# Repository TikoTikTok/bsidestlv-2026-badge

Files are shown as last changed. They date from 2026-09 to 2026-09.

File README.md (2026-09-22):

# BSidesTLV 2026 Badge

Everything for the BSidesTLV 2026 badge: two KiCad boards, the RP2040 firmware
that runs on it, and the online puzzle challenge — *Alice in AI Land* — that the
badge is used to play.

<p align="center">
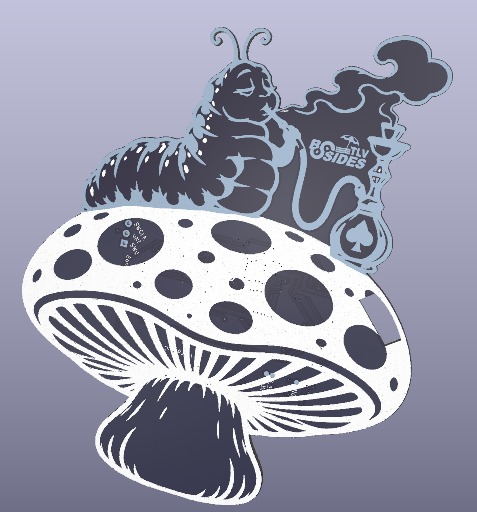
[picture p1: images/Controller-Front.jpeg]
The badge, front
  
</p>

```
index.html         the challenge - static site, served from the repo root
styles.css  src/  stages/  assets/
hardware/          KiCad projects (CERN-OHL-S-2.0)
  badge/             "BSidesTLV2026 Alice Controller" - RP2040 handheld, 14 buttons, USB-C
  soldering-kit/     555 + CD4017 LED chaser, the soldering workshop kit
software/          everything that builds the above, but is not served (MIT)
  controller/        RP2040 firmware - enumerates as a DualShock 4
  tools/             slicing and generation, writes into ../assets/
  references/        the source sheets the art was cut from
  legacy/  docs/
```

## The challenge

*Alice in AI Land* is a boulder-pushing puzzle game whose answer is a **program**.
Five stages. The first two are played by hand on the badge. Stage 3 is a
wall: the board is hidden before a human could read it and the move budget
exceeds human input bandwidth, so the only way through is to drive the game with
a script. The game hands you the protocol in stage 2 and dares you to use it.

The simulation is deterministic — 60 ticks/second, one input bitmask per tick,
same seed plus same input trace gives the same outcome byte for byte — which is
what makes it scriptable, replayable and verifiable.

It lives at the repository root — `index.html`, `styles.css`, `src/`, `stages/`
and `assets/` — as plain static files. No server, no build step, every path
relative, so it works at a domain root or under `/<repo>/` unchanged.

```
./serve.sh          # http://localhost:8080, the same files Pages serves
npm run verify      # proves both stages are solvable
```

[`.github/workflows/pages.yml`](.github/workflows/pages.yml) stages those five
paths and publishes them; set Settings -> Pages -> Source to "GitHub Actions"
once and pushes to `main` that touch the site deploy themselves. It stages
rather than uploading the repo so the artifact stays ~4MB instead of ~34MB —
`hardware/` and `software/` are not part of the site.

ES modules need `http://`, not `file://`. That is the only reason a local
server exists.

- [`software/README.md`](software/README.md) — asset set, slicing tools, how every sprite was cut
- [`software/docs/GAME_DESIGN.md`](software/docs/GAME_DESIGN.md) — stages, tick model, protocol

## The hardware

| Board | What | Key parts |
|---|---|---|
| [`hardware/badge/`](hardware/badge) | "BSidesTLV2026 Alice Controller" v0.4 — the badge itself, and the controller the challenge is played on. D-pad, A/B/X/Y, Start/Select, reset and BootSel, all on one side. Cut to the outline of the Caterpillar's mushroom. | RP2040, W25Q128JVS, AMS1117-3.3, USB-C |
| [`hardware/soldering-kit/`](hardware/soldering-kit) | Through-hole LED chaser for the soldering workshop. Beginner-friendly: DIP, axial, CR2032. | TLC555P, CD4017BE, 4x LED, 500k trimmer |

<table>
<tr>
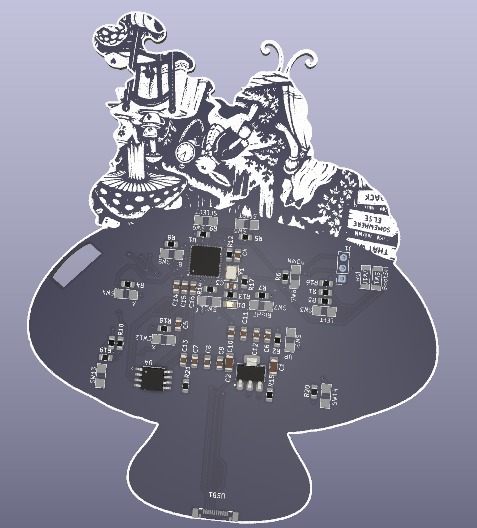
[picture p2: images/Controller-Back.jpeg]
The badge, back
  <td align="center" width="50%"></td>
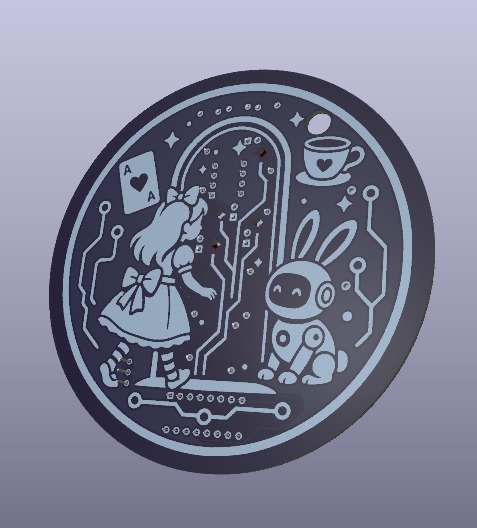
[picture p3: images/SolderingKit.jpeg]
The soldering kit
  <td align="center" width="50%"></td>
</tr>
<tr>
  <td align="center"><b>badge, back</b> — the RP2040, flash, regulator and the button matrix</td>
  <td align="center"><b>soldering kit</b> — Alice, the White Rabbit and the looking glass</td>
</tr>
</table>

Each project carries its own `production/` directory with the fabrication
package: BOM, positions, designators and IPC netlist.

See [`hardware/README.md`](hardware/README.md) for opening, plotting and
re-fabricating the boards.

## The firmware

[`software/controller/`](software/controller) is the RP2040 firmware. It
presents the badge to a host as a **wired DualShock 4**, which is what makes it
work on an iPhone — iOS only binds controllers it recognizes by USB VID/PID, so
a generic HID gamepad enumerates and is then ignored. Every other host
understands the same report.

```
cd software/controller
mkdir build && cd build
cmake -DPICO_SDK_PATH=/path/to/pico-sdk ..
make -j                              # -> build/controller.uf2
```

Hold `BootSel` while plugging in USB-C, then copy `controller.uf2` onto the
`RPI-RP2` drive that appears. It also builds and runs on a stock Raspberry Pi
Pico, which is the easiest way to try the firmware without a badge.

Full pin map and HID report layout:
[`software/controller/README.md`](software/controller/README.md).

## Licences

- **Software** — MIT, see [`LICENSE`](LICENSE). Covers `software/` and the
  Python/Node tooling under `hardware/soldering-kit/tools/`.
- **Hardware** — CERN-OHL-S-2.0, see [`hardware/LICENSE`](hardware/LICENSE).
  Covers both KiCad projects and every gerber, plot and production package
  under `hardware/`.

Third-party symbols and footprints vendored under
`hardware/badge/libs/lcsc/` keep their own upstream terms.

## Contributing

See [`CONTRIBUTING.md`](CONTRIBUTING.md).

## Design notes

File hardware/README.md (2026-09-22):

# Hardware

Two KiCad 9 projects. Each is self-contained: open the `.kicad_pro` in KiCad
and everything it needs is beside it.

| Directory | Project | What it is |
|---|---|---|
| `badge/` | `PhoneController` / "BSidesTLV2026 Alice Controller" v0.4 | The badge, and the controller the online challenge is played on: D-pad, A/B/X/Y, Start/Select, reset and BootSel, USB-C, 16 MB external flash, SWD header. |
| `soldering-kit/` | `BSidesTLV26TinyBadge` | The soldering workshop kit: a TLC555 astable clocking a CD4017 decade counter that chases four LEDs. All through-hole — DIP sockets, axial resistors, a 3296W trimmer for the rate and a CR2032 holder — so a first-time solderer can build it. |

The project files inside `badge/` are still named `PhoneController.*` — that
was the board's working name before it became the badge. The directory says what
it is; renaming the KiCad project would break every path that refers to it.

## Opening

KiCad 9. Nothing here needs a plugin to *view*; the production packages were
generated with [Fabrication Toolkit](https://github.com/bennymeg/Fabrication-Toolkit),
whose settings live in each project's `fabrication-toolkit-options.json`.

`badge/libs/lcsc/` vendors the symbol, footprint and 3D model for the USB-C
connector imported from LCSC. `fp-lib-table` and `sym-lib-table` point at it
with project-relative paths, so the project moves without breaking.

## Fabrication

Each project ships the package it was last ordered with:

```
<project>/production/
  bom.csv           designator -> footprint, quantity, value, LCSC part number
  positions.csv     pick-and-place
  designators.csv
  netlist.ipc       IPC-D-356 netlist, for bare-board electrical test
  <project>.zip     the gerbers as sent to the fab
```

`badge/gerbers/` additionally keeps the loose gerber set and job file, and
`badge/output/` the per-layer SVG plots.

To regenerate rather than reuse: open the board, run Fabrication Toolkit, and
the directory is rewritten.

## Generating the soldering-kit schematic

`soldering-kit/tools/` builds `BSidesTLV26TinyBadge.kicad_sch` from code rather
than by hand:

```
python3 soldering-kit/tools/build_badge_sch.py
```

| File | What |
|---|---|
| `build_badge_sch.py` | The circuit itself: CR2032 -> TLC555 astable -> CD4017 -> 4 LEDs, with the part choices argued in its docstring |
| `schbuild.py` | Places symbols, resolves absolute pin coordinates, draws wires |
| `symlib.py` | Pulls a symbol out of a `.kicad_sym` library, flattening `(extends ...)` so the embedded copy is self-contained |
| `ksexpr.py` | Dependency-free S-expression reader/writer that round-trips KiCad files |
| `verify_xf.py` | Regression check for the pin transform against a pre-change schematic passed as `argv[1]` |

These are software, not hardware: MIT, under the root `LICENSE`.

## Autorouting

`badge/freerouting.dsn` is the Specctra export used with
[Freerouting](https://github.com/freerouting/freerouting). It is an export, not
a source of truth — the `.kicad_pcb` is.

## What is deliberately not here

KiCad's own rolling archives (`*-backups/`, `production/backups/`), the
`fp-info-cache`, `*.kicad_prl` per-user state and editor lock files are all
ignored — git is the history now. See the root `.gitignore`.

## Firmware

The badge's firmware is not here — it is a Pico SDK project at
[`../software/controller/`](../software/controller), under MIT like the rest of
the software.

## Licence

CERN-OHL-S-2.0, see [`LICENSE`](LICENSE). Vendored third-party libraries under
`badge/libs/` keep their upstream terms.

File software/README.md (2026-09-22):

# Alice in AI Land — asset set

Characters and items for a boulder-pushing puzzle game, cut from the supplied
reference sheets. Everything on the page is real art: nothing is generated.

```
./serve.sh        # http://localhost:8080
```

ES modules need `http://`, not `file://`. That is the whole build system.

## Layout

The site itself is at the repository root — `index.html`, `styles.css`, `src/`,
`stages/`, `assets/` — because that is what GitHub Pages serves. This directory
is everything that produces it and is never published:

```
tools/        slicing and generation, writes into ../assets/
references/   the source sheets the art was cut from (15MB)
docs/         design doc
legacy/       the generated-sprite pass the page no longer loads
controller/   RP2040 firmware for the badge - a separate CMake project
```

Run the tools from the repository root, where `package.json` lives:

```
npm run verify      # both stages solvable
npm run validate    # legacy sprite/frame integrity
./serve.sh          # http://localhost:8080
```

`controller/` is the firmware the badge runs — a Pico SDK CMake project with its
own [README](controller/README.md), unrelated to those npm scripts.

Deployment is [`.github/workflows/pages.yml`](../.github/workflows/pages.yml).

## What's here

| Path | What |
|---|---|
| `assets/characters/<name>/` | 24 walk frames (8 directions x 3), 48x48 RGBA, + `<name>.json` |
| `assets/items/` | 44 item PNGs, 48x48 RGBA, + `items.json` |
| `assets/tiles/` | 77 floor, wall, hedge, rail, door and button PNGs, 48x48 RGBA, + `tiles.json` |
| `software/references/` | The supplied reference sheets every asset was cut from |
| `tools/slice-walk-grid.py` | Cuts a character sheet into walk frames |
| `tools/slice-item-sheet.py` | Cuts `software/references/assets-reference.png` into items |
| `tools/slice-tile-sheet.py` | Cuts `software/references/tiles-reference.png` into tiles and props |
| `tools/build-walk-manifest.mjs` | Indexes a character folder into `<name>.json` |
| `tools/sheet-maps/` | Hand-picked cell maps for sheets that are not clean grids |
| `tools/pnglib.py` | Dependency-free PNG read/write + black-background keying |
| `tools/preview/` | Look at what a slice produced: contact sheets, sheet cells, side-by-side frames |
| `index.html`, `src/`, `styles.css` | The page: two playable stages, walk cycles, tile and item sheets |

## Characters

| character | folder | source sheet | how |
|---|---|---|---|
| Alice | `alice2/` | `software/references/alice-reference3.png` | cut by hand |
| White Rabbit | `rabbit/` | `software/references/white-rabbit-reference.png` | `slice-walk-grid.py` (wide) |
| Mad Hatter | `hatter/` | `software/references/mad-hatter-reference.png` | `slice-walk-grid.py` + cell map |
| Red Queen | `queen/` | `software/references/queen-reference.png` | `slice-walk-grid.py` + cell map |
| Cheshire Cat | `cheshire/` | `software/references/cheshire-reference.png` | `slice-walk-grid.py --layout pairs` |

Frames are `<dir><frame>.png` (`s1.png`, `N1.png`, `SW2.png` - case does not
matter). Frame 1 stands, 2 and 3 are the walk pair; the manifest's `cycle` runs
them as stand → step → stand → other step.

```
python3 software/tools/slice-walk-grid.py software/references/white-rabbit-reference.png rabbit
node software/tools/build-walk-manifest.mjs assets/characters/rabbit rabbit
```

**Layouts.** `--layout wide` (default) is 8 columns x 3 rows, one column per
direction. `--layout pairs` is 6 columns x 4 rows — two directions per row —
which is how the Cheshire sheet is arranged.

**Sheets without an alpha channel** (queen, cheshire) sit on pure black. The
tool floods in from the border through *pure* black only, so the background goes
and the character's near-black outline stays; nothing inside the figure is
reachable, so it cannot punch holes.

**Pose sheets.** The hatter and queen sheets are not direction grids — the
facing drifts across each row. `tools/sheet-maps/<name>.json` names the cells to
use per direction, which are mirrored, and which are aliases:

```json
{ "cells":  { "n": [[1,1],[1,8],[1,7]], "sw": [[2,3],[2,2],[2,1]] },
  "mirror": { "ne": "nw", "se": "sw" },
  "alias":  { "w": "sw", "e": "se" } }
```

Direction follows the **body**, not the head — in these sheets a character often
walks one way while glancing back over their shoulder. Reading the face gets the
mapping backwards.

Known compromises, both from the source sheets: the hatter has no true profile,
so his E and W reuse the diagonals; the queen has only two usable side poses, so
her W repeats a frame.

## Tiles

```
python3 software/tools/slice-tile-sheet.py
```

Cuts both tile sheets - `software/references/tiles-reference.png` and `software/references/assets-reference2.png` - into
77 assets under `assets/tiles/`, with one merged manifest and two fit policies,
because these are two kinds of art:

- **tile** (`floor`, `wall`) fills the whole 48x48 cell — these *are* the grid,
  and a gap around them would read as a seam.
- **prop** (`door`, `button`) keeps its aspect and sits on the cell floor, all
  sharing one scale factor so a button stays smaller than a door.

The sheets carry a faint coloured halo around some sprites (alpha 1-4, stray
blues and yellows). Weighting the resample by alpha makes it contribute
essentially nothing, so no keying or clean-up pass touches the colours.

Rows are found from the pixels, except on the second sheet where the walls in
neighbouring rows nearly touch; those band boundaries are given explicitly,
found from the row-occupancy profile rather than from gaps.

**Not every wall piece fills its cell.** Pillars, posts and rails are narrower
than 48px, so the stages draw a floor in every cell first and composite the
wall art on top. Without that, the gap around a pillar is just background
showing through.

## Items

```
python3 software/tools/slice-item-sheet.py
```

Rows and the items inside each row are found from the pixels, so the last row
holding eight instead of six needs no special case. Every item is scaled by one
shared factor — a key stays small next to a boulder — then centred on the bottom
of a 48x48 frame, the same size as a character frame, so items and characters
drop onto the same grid with no per-asset fiddling.

Categories: `scenery` (rocks, mushrooms), `book`, `teapot`, `teacup`, `potion`,
`token` (keys and cards). Names are in `assets/items/items.json`.

## The stage and the solver

`stages/tea-party.js` is a playable Sokoban-with-extras room. `src/puzzle.js`
holds the rules and the solver; `tools/verify-stage.mjs` runs the same solver
from the command line.

```
node software/tools/verify-stage.mjs stages/tea-party.js
```

```
A Mad Tea Party - 13x9, 3 rocks, 3 buttons, 1 gate(s), 1 lever(s)
solved in 106 moves (330ms, 12520 nodes, 12520 states)
gate: load-bearing - unsolvable when welded shut
```

The verifier does three things worth having:

1. **Replays the solution through the rules.** A solver that returns a path the
   game rejects is a bug, and this catches it — it caught one where the search
   walked Alice through the door cell.
2. **Proves the gate matters.** It re-solves the stage with the gate welded shut
   and the lever removed. "The solver happened to use it" is not the same as
   "the puzzle needs it" — a route that merely exists is not a mechanic.
3. **Reports the shortest solution**, which is the yardstick the tick budgets in
   `docs/GAME_DESIGN.md` are set against.

The **Solve** button on the page runs that same search in the browser and plays
back what it finds. It is not a recorded answer: press it after moving Alice
around by hand and it solves from wherever she is, or tells you the position is
already lost.

### How the search stays fast enough for a button

A step-by-step BFS explores ~750k states on this stage and takes a second or
more. Three changes bring it to ~12k states and ~330ms:

- **Dead squares.** Pull a rock backwards from every button; any square not
  reached that way can never deliver a rock, so a state that puts one there is
  abandoned.
- **Search over pushes, not steps.** Walking between pushes is bookkeeping, not
  a decision. The search branches only where the puzzle does: which rock, which
  way, and when to throw the lever.
- **States keyed by region.** Two spots Alice can walk between without touching
  anything are the same position as far as the puzzle is concerned. Working out
  which region a state belongs to costs a flood fill, so it happens once per
  node popped rather than once per edge considered.

The trade: costs are measured from where Alice actually stands, so the result is
near-optimal rather than provably optimal. Worth two orders of magnitude.

## The timed stage

`stages/queens-gauntlet.js` adds the thing the first stage is missing: a clock.
Every tick the cast advances one cell along a fixed loop, so a plan is not a
route but a schedule.

```
node software/tools/verify-chase.mjs stages/queens-gauntlet.js
```

```
The Queen's Gauntlet - 9x8, 2 rocks, 3 hazards, world repeats every 30 ticks
  queen: 10-tick loop, sight 3
  cheshire: 6-tick loop
  rabbit: 6-tick loop
par 64 ticks (5 of them waiting) - 20.5s at 320ms/tick
hazards: cost 23 extra ticks over an empty room (par 41)
```

`src/chase.js` holds the rules. What makes it searchable is that the hazards
are deterministic and periodic: the world's entire future is
`phase mod period`, so a state is `(Alice, rocks, lever, phase)` and plain
breadth-first search returns the fewest ticks — which is also the stage's par,
the exact number of correct inputs a player has to land.

Why it is hard by hand, and not merely fiddly:

- **One corridor joins the halves and the Queen walks it**, looking three cells
  ahead. Both rocks and Alice have to cross it several times, so every crossing
  is a window rather than a route.
- **Standing still is a move.** The shortest solution waits five times; a player
  who only knows how to move cannot express the plan.
- **Being seen ends the run**, so 64 inputs have to be correct *and* on time.
  One late press and it starts over.

The verifier re-solves the room with the cast removed and reports the
difference. If the hazards cost zero ticks they are scenery, which is exactly
what the first three layouts turned out to be — the map was open enough to
route around everyone.

## The page

Both stages pick their look from a theme: each map character maps to a list of
tiles, and which one a cell gets is a hash of its coordinates - deterministic,
so a room looks hand-dressed but never shuffles between frames. The tea party
is a walled garden, the gauntlet is the Queen's hall.

- **Stage — A Mad Tea Party** — the untimed puzzle. Arrow keys or WASD, R to
  reset, Solve to watch the solver do it. `?autosolve=tea` starts it on load.
- **Stage — The Queen's Gauntlet** — the timed one. The clock runs whether you
  act or not; space waits, R restarts, and the red tint is what the Queen can
  see this tick. `?autosolve=chase` starts it on load.
- **8-way walk cycles** — a tab per character, a compass of all eight directions
  each running its own cycle, and a large view you drive by clicking or with the
  arrow keys / WASD (hold two for a diagonal). `?walk=queen` opens on one.
- **Tiles** and **Items** — every asset, filterable by category, click a name
  to copy it.

Adding a character: drop 24 frames in `assets/characters/<name>/`, run the
manifest tool, add `{ id: '<name>', label: '<Name>' }` to `WALK_CHARACTERS` in
`src/gallery.js`.

## Looking at a slice

Slicing is guesswork until you look at the result, so the review tools are in
the repo rather than improvised each time:

```
python3 software/tools/preview/contact.py assets/characters/queen out.png 3
python3 software/tools/preview/cells.py   software/references/queen-reference.png       out.png
python3 software/tools/preview/compare.py assets/characters/queen   out.png w1,e1,sw1,se1
```

- **contact** renders a whole folder as one sheet — 8x3 for a character,
  manifest order for items and tiles.
- **cells** lays a reference sheet out cell by cell in sheet order, indexed
  `[row, col]` from 1. This is the tool for writing a `sheet-maps/*.json`: it
  shows the grid the way the map file indexes it, so the cells can be read off
  rather than guessed at.
- **compare** puts named frames side by side, big. For settling which way a
  sprite faces — the question that got the queen's mapping wrong three times.

## Legacy

An earlier pass generated placeholder sprites in code. It lives in `legacy/`
(`legacy/assets/sprites.*.js`, `legacy/src/pixel.js`, `legacy/dist/`) and is
driven by `tools/gen-*.mjs`, `tools/export-png.mjs` and `tools/validate.mjs`.
The page no longer loads any of it, and it is outside `` so none of it is
published. Kept only so nothing is deleted without asking — safe to remove.

## Licence

MIT — see the repository root [`LICENSE`](../LICENSE). The hardware this runs on
lives in [`../hardware/`](../hardware) under CERN-OHL-S-2.0.

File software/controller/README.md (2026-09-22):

# Controller firmware

Firmware for the BSidesTLV 2026 badge - the "BSidesTLV2026 Alice Controller" v0.4, a USB HID game
controller built on the RP2040. It also builds and runs unchanged on a stock
Raspberry Pi Pico (RP2040 / RP2350), which is the easiest way to try it without
a badge.

The board it targets is [`hardware/badge/`](../../hardware/badge); this
directory is only the firmware. It enumerates as a **wired DualShock 4**, so
phones, PCs and emulators recognize it with no driver or app - including
iPhones. The button layout mimics a Game Boy Color: a 4-way D-pad plus `A`,
`B`, `X`, `Y`, shoulder buttons (`SR`/`SL`), and `START` / `SELECT`.

### Why DualShock 4 and not a generic gamepad

A plain HID gamepad descriptor works on Android, Windows, macOS and Linux, but
is **invisible on iOS/iPadOS**: Apple's GameController framework only attaches
to controllers it recognizes by USB VID/PID (MFi, Xbox Wireless, DualShock 4 /
DualSense, Switch Pro). A generic gamepad enumerates and is then ignored - no
app can see it. Presenting the DualShock 4's identity and input report makes an
iPhone bind a real controller profile, and every other host understands it too.

## Wiring

All buttons are **active-low**: wire each button between its GPIO and `GND`.
The firmware enables the RP2040's internal pull-ups, so external pull-up
resistors are optional (the description below assumes you already have them).

| Function | GPIO  |
| --- | ----- |
| D-pad DOWN | 0 |
| D-pad RIGHT | 1 |
| D-pad UP | 2 |
| D-pad LEFT | 3 |
| B | 4 |
| A | 5 |
| X | 20 |
| Y | 21 |
| SR (R shoulder) | 22 |
| SL (L shoulder) | 25 |
| START | 23 |
| SELECT | 24 |
| Status LED | 8 |

The status LED (GPIO8, active-high through a current-limiting resistor):

- **Blinks @ 250 ms** — USB not mounted (waiting for host).
- **Blinks @ 1 s** — USB suspended.
- **Solid while pressed** — mounted and running; lights up whenever any button
  is held, as live input feedback.

## HID mapping

The device sends DualShock 4 input report `0x01` (64 bytes) every 5 ms:

| Physical button | DualShock 4 control |
| --- | --- |
| D-pad | Hat switch (8 directions) |
| A | Cross |
| B | Circle |
| X | Square |
| Y | Triangle |
| SR (R shoulder) | R1 |
| SL (L shoulder) | L1 |
| START | Options |
| SELECT | Share |

There are no analog sticks or triggers on the board, so both sticks report
centered (`0x80`) and both triggers report released. Opposing D-pad directions
cancel out (e.g. pressing UP and DOWN together reports centered) so no
impossible diagonal is ever sent.

The report is streamed continuously rather than only on change: the real
controller does the same, and the report counter in `buttons2` has to keep
advancing for drivers that watch it for a stalled device. Feature reports the
host probes during attach (IMU calibration `0x02`, MAC `0x12`, version `0xA3`)
are answered with well-formed placeholder data - see
`tud_hid_get_report_cb()` in `src/usb_descriptors.c`.

## Building

Prerequisites: `cmake` (>= 3.13), the `arm-none-eabi` GCC toolchain, and a
checkout of the [pico-sdk](https://github.com/raspberrypi/pico-sdk) with its
submodules (TinyUSB) initialized.

`CMakeLists.txt` falls back to `../pico-sdk` relative to this directory, which
inside this repository would be `software/pico-sdk` and is almost certainly not
where your SDK lives. Point at it explicitly:

```bash
# from software/controller/
mkdir build && cd build
cmake -DPICO_SDK_PATH=/path/to/pico-sdk ..
make -j
```

`PICO_SDK_PATH` works as an environment variable too, if you already export it.

The first configure fetches `picotool` from git and builds it, so it needs
network access. If you have one already built, reuse it and skip that:

```bash
cmake -DPICO_SDK_PATH=/path/to/pico-sdk -Dpicotool_DIR=/path/to/picotool ..
```

To target a different board (e.g. a Pico 2 / RP2350), pass the board at
configure time:

```bash
cmake -DPICO_BOARD=pico2 -DPICO_SDK_PATH=/path/to/pico-sdk ..
```

The build produces `build/controller.uf2`, about 41KB.

## Flashing

1. Hold the **BOOTSEL** button while plugging the Pico into USB; it mounts as a
   mass-storage drive (`RPI-RP2`).
2. Copy `controller.uf2` onto it. The board reboots and re-enumerates as a
   "Wireless Controller" by "Sony Interactive Entertainment" - see the VID/PID
   note below.

On the badge, BOOTSEL is the button silkscreened `BootSel`; hold it while
plugging in USB-C.

After flashing, plug it into a phone (via USB-OTG / USB-C). It should appear as
a connected gamepad, ready for the challenge at the repository root, for
emulators, or any app that supports HID controllers.

## Notes

- Reports Sony's VID `0x054C` / PID `0x09CC` (DualShock 4 CUH-ZCT2U). That is
  what buys iOS support; it is also not a VID/PID this project owns, so do not
  ship hardware with it.
- **Hardware:** the USB-C receptacle needs a 5.1k Rd pulldown on **both** CC1
  and CC2. CC1 has one (R15 on the controller board); CC2 was left floating,
  which means a USB-C iPhone will not turn on VBUS in one of the two cable
  orientations. `hw/usb/PhoneControllerUSB.kicad_sch` now carries `R1` (5.1k,
  CC2 to GND) - the matching `.kicad_pcb` still needs "Update PCB from
  Schematic" plus placement and routing of that one 0805.
- The RP2040 USB enumeration errata fix (RP2040-E5) is enabled in
  `CMakeLists.txt`; it reserves GPIO15 internally on RP2040 boards.

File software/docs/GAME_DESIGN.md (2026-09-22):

# Alice in AI Land — game design

A puzzle game where the answer is a *program*.

Five stages. The first two are played by hand. Stage 3 is a wall: the board is
hidden before you could read it and the move budget exceeds human input
bandwidth. From there the only way through is to drive the game with a script.
The game does not hide that — it hands you the protocol in stage 2 and dares
you to use it.

---

## 1. Premise

Alice falls into AI Land. Every character is a machine that wants something
from her, and the only currency is moves:

| character | role in play |
|---|---|
| **Alice** | the player's avatar |
| **White Rabbit** | the clock — he paces a fixed route and gates open/close as he passes |
| **Mad Hatter** | rewrites rules: reading his books changes what a button does |
| **Red Queen** | the deadline — she looks at the board on a schedule and removes what offends her |
| **Cheshire Cat** | hides state; after he fades, the board is only visible through the protocol |

---

## 2. Controls

Eight-way movement, because the sprite sheets are eight-way. On a d-pad,
diagonals are two directions held together.

| input | verb |
|---|---|
| D-pad / arrows | step (and push what is in front) |
| **A** | interact — pick up, place, read, unlock |
| **B** | dash — two tiles, does not push |
| **X** | mark / recall — drop a Cheshire mark, press again to swap places with it |
| **Y** | tick-step — advance the world one tick without moving (a wait primitive) |

`Y` matters more than it looks. Puzzles are timing puzzles; a script needs a
no-op that still advances the world, and a human needs a way to stall.

---

## 3. The tick model

Everything is deterministic and discrete. This is what makes the game
scriptable, replayable and verifiable.

- The sim runs at **60 ticks/second**.
- Each tick consumes exactly **one input bitmask**. No input = empty mask.
- Movement has a **cooldown** in ticks, per stage. A move is accepted only when
  the cooldown has expired, so mashing gains nothing.
- Same seed + same input trace = same outcome, byte for byte.

| stage | move cooldown | effective move rate |
|---|---|---|
| 1 | 8 ticks | 7.5 moves/s |
| 2 | 6 ticks | 10 moves/s |
| 3 | 3 ticks | 20 moves/s |
| 4 | 2 ticks | 30 moves/s |
| 5 | 2 ticks | 30 moves/s |

A human sustains roughly **4–6 accurate directional inputs per second** and
reacts to new information in **~250 ms**. Those two numbers are the design
budget: stages 1–2 sit under them, stages 3–5 sit far above.

---

## 4. The Looking Glass protocol

**The server is the game.** It owns the seed, runs the sim, and is the only
authority on state. The browser is just one client rendering what it is told.
A player's script is a client with exactly the same rights. There is no
privileged path, so there is nothing to cheat around — and nothing to
reverse-engineer either. The challenge is the puzzle, not the plumbing.

```
ws://localhost:7777/looking-glass
```

Server → client, once per tick:

```json
{ "tick": 412, "stage": 3, "seed": "b5f1…", "deadline_ms": 14,
  "board": { "w": 9, "h": 9, "tiles": "…", "entities": [ … ] },
  "alice": { "x": 4, "y": 6, "cooldown": 0, "carrying": null },
  "timer": { "remaining_ticks": 58 }, "status": "running" }
```

Client → server:

```json
{ "tick": 412, "buttons": ["up", "left", "a"] }
```

Rules:

- An input is bound to the tick it names. Late inputs are dropped, not queued —
  otherwise a slow script would drift and blame the game.
- One input per tick, maximum. Spam is not a strategy.
- `deadline_ms` says how long is left in the current tick, so a script can
  decide whether to answer now or skip.

In-fiction, this is the Hatter's book. Stage 2 ends by handing it over.

---

## 5. Where the wall is, and why it is fair

Stage 3 is the point of the game, so it has to be *obviously* impossible rather
than merely annoying. It fails a human on two independent axes at once:

1. **You cannot see it.** The board is revealed for 0.5 s, then Cheshire fades
   it. After that the only way to read the board is the protocol.
2. **You cannot type it.** The optimal solution is ~26 moves and the window is
   72 ticks (1.2 s). That is ~20 moves/second, sustained, with zero mistakes.

And it cannot be beaten by memorising: **the board is reseeded on every
attempt**. A recorded input trace is worth nothing on the next run.

What it demands of a script is modest and honest: read the state, run a
breadth-first search over a few thousand positions, emit moves on the clock.
Any language, any library. Every stage is validated by a **reference solver**
that must finish in **under 60 % of the tick budget** — if the reference cannot
do it comfortably, the stage is retuned, not shipped.

---

## 6. The five stages

### Stage 1 — Down the Rabbit Hole
*No clock. Teaches the verbs.*

- 12×8 room. Push three rocks onto three card plates, take `key_heart`, open
  the heart door.
- The Rabbit paces a corridor and opens a gate as he passes it — the first hint
  that the world moves on its own schedule.
- **Win:** reach the door. **Manual:** trivially.

### Stage 2 — A Mad Tea Party
*90-second clock. Teaches that rules are data.*

- Place four teacups on saucers of matching suits. The teapot pours along a
  channel; pour order matters, so the puzzle has a dependency graph.
- Mushrooms resize Alice: small fits through gaps but cannot push; large pushes
  but blocks doors.
- Four books on pedestals. Reading each with **A** prints a line of the Looking
  Glass spec and rebinds one button. The fourth book is the protocol itself.
- **Win:** four cups placed, then enter the 4-button code the books spell out.
- **Manual:** yes — this is the last stage that is.

### Stage 3 — The Card Soldiers' Drill
*The wall. 1.2 s, board hidden, reseeded every attempt.*

- 9×9, randomised. Four suit cards, four matching plates, walls between.
- Cheshire fades the board after 0.5 s. From then on, state comes only over the
  protocol.
- Optimal ≈ 26 moves, budget 72 ticks at 3-tick cooldown = 36 moves. Room for a
  slightly suboptimal plan, none for a slow one.
- Failure resets instantly with a fresh seed.
- **Manual:** blocked twice over — cannot see it, cannot type it.
- **Script:** read board → BFS over cards×positions → emit.

### Stage 4 — The Queen's Croquet
*Four boards, one Alice. 2 s.*

- Four 7×7 quadrants. **One input drives all four boards at once.** Alice exists
  in each; a move that helps quadrant 1 may ruin quadrant 3.
- **X** cycles an input mask so a quadrant can be frozen out for a few ticks —
  the release valve that makes it solvable, and the thing a naive solver misses.
- Needs search over the *product* state space, not four searches. ~40 moves in
  120 ticks.
- **Manual:** no. **Script:** BFS/IDA* over the joint state, mask included.

### Stage 5 — The Trial
*Adversarial. Replan or lose.*

- The Queen edits the board every 12 ticks, and what she edits is a function of
  **your last four inputs** plus the seed. A precomputed plan is invalid the
  moment it starts executing.
- Five rounds, each with a new target. Between rounds the geometry rotates.
- Finale: the door wants an 8-button sequence derived from the board state by a
  rule printed in the last book — a checksum over card suits and plate
  positions. You must *compute* it from live state, not path to it.
- Budget: ~150 ms of thinking per round, i.e. a replanning loop, not a plan.
- **Win:** the flag, `HMAC(seed ‖ trace_hash ‖ server_secret)`.

---

## 7. Assets → mechanics

Everything below already exists in `assets/`.

| asset | mechanic |
|---|---|
| `rock_*` | pushable blocks; `rock_pile` is immovable wall |
| `mushroom_red_*` / `mushroom_blue_*` | grow / shrink Alice |
| `book_*` | rule rewrites; `book_open` is the protocol spec |
| `teapot_*` | pour source, fills a channel |
| `teacup_*` | must reach the matching suit saucer |
| `potion_*` | timed effects: speed, phase, freeze (stage 4–5 only) |
| `key_*` | opens the lock of its suit |
| `card_*` | pressure plates and the Queen's guards |
| walk cycles | Alice, and the four characters as scheduled hazards |

Tiles (`assets/tiles/`) cover the rest:

| asset | mechanic |
|---|---|
| `floor_*` | ground; `floor_carpet_red` marks the Queen's kill zone in stage 5 |
| `wall_*`, `hedge_*` | impassable; `hedge_rail` blocks Alice but not sight |
| `door_*_closed` / `_open` | suit-locked exits, one sprite per state |
| `button_*_up` / `_down` | pressure plates, one sprite per state |
| `lever_up` / `lever_down` | toggles that stay where you put them |

Still missing: nothing blocking. A one-tile pit or hole would be useful for the
push-into-the-gap puzzles, but a dark floor tile stands in for now.

---

## 8. Anti-cheat and the flag

- The server simulates; the client only renders. `win()` does not exist on the
  client because winning is a server-side judgement.
- Every session gets a fresh seed. Stage 3+ reseeds per attempt.
- The flag is an HMAC over the seed and a hash of the accepted input trace, so a
  flag proves a specific run actually happened.
- The server replays the trace before issuing it. A trace that does not reach
  the goal, or that beats the physical minimum tick count, is rejected.
- **Practice mode** (`?practice=1`) runs at quarter speed with a fixed seed and
  issues no flag — for learning the mechanics without grinding.

---

## 9. Build order

1. **Sim core** — deterministic, headless, no rendering. Tiles, entities, push
   resolution, cooldowns, win conditions. Unit-tested by replaying traces.
2. **Server + protocol** — sessions, seeds, WS, HMAC. The browser talks to it
   like any other client from day one.
3. **Browser client** — render with the existing assets, keyboard + gamepad.
4. **Stages 1–2** — the human-playable half, including the books that teach the
   protocol.
5. **Reference solvers** — one per stage 3–5. These are the acceptance test:
   no stage ships until its solver clears it in under 60 % of budget.
6. **Stages 3–5** — content, then tune the budgets against the solvers.
7. **Practice mode, leaderboard** — rank by total ticks, which rewards better
   solvers rather than faster typing.

## 10. Open questions

- **Gamepad vs script parity** — a gamepad player on stages 1–2 and a script on
  3–5 is the intended arc. Worth checking that stage 2 is still fun on a pad.
- **Latency floor** — the WS round trip has to fit inside a 16 ms tick. If
  players run scripts on the same machine this is fine; over a network it is
  not. Ship it as a local server.
- **Difficulty of stage 4's mask** — the input mask may be one idea too many.
  It exists to make the joint search tractable; if the solver copes without it,
  cut it.
- **How much to spoon-feed** — stage 2 handing over the full protocol may be too
  generous for a CTF audience. The alternative is to document only the endpoint
  and let them read the frames.

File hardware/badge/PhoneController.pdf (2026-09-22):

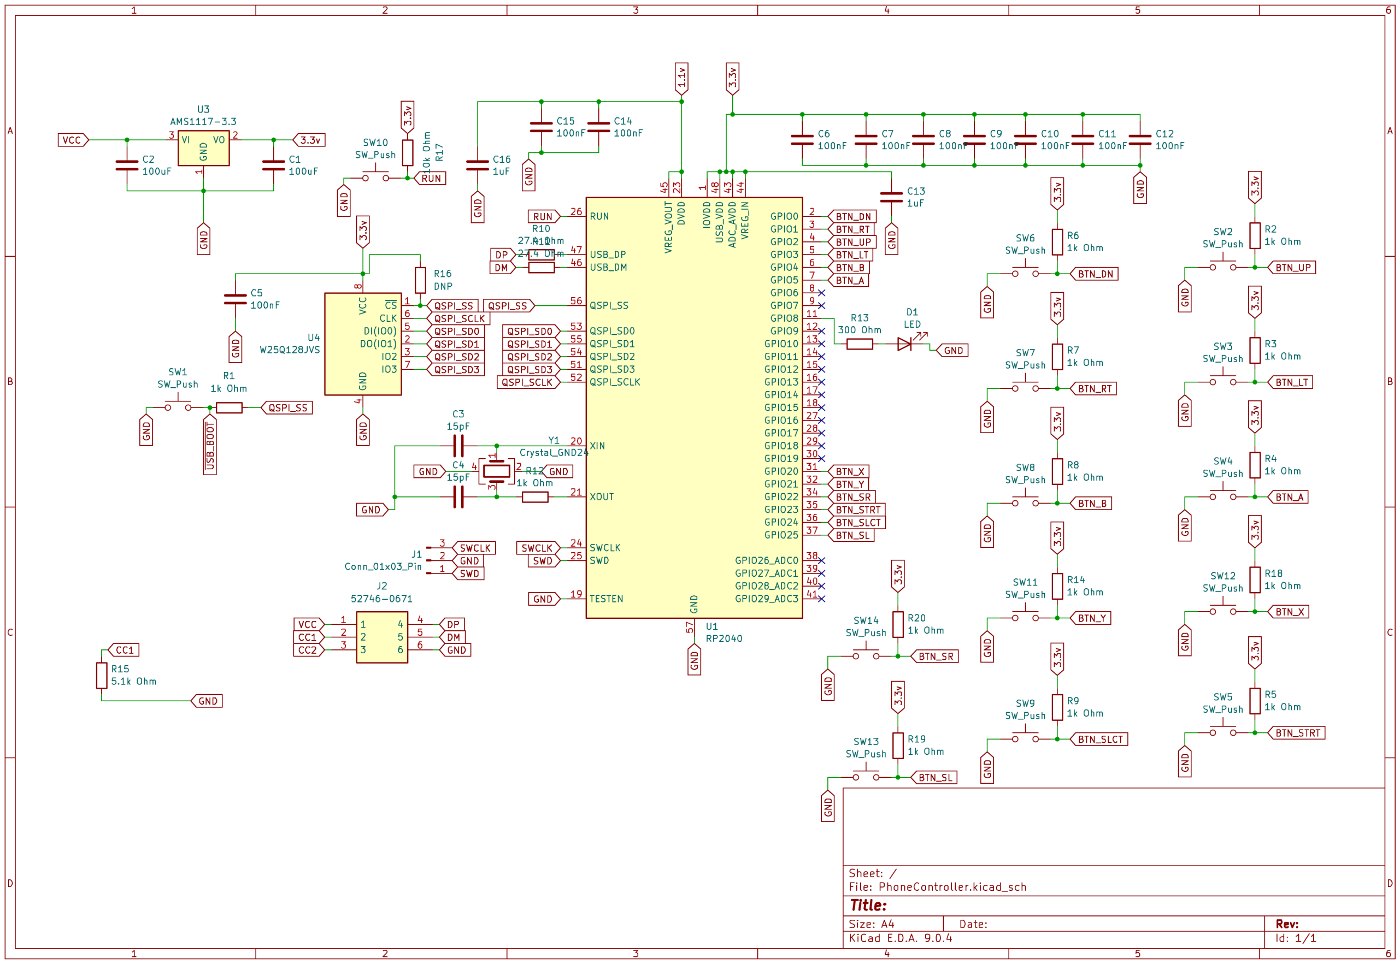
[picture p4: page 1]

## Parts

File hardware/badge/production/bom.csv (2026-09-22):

Designator | Footprint | Quantity | Value | LCSC Part #
C1, C2 | 1206 | 2 | 100uF | C15008
C10, C11, C12, C14, C15, C5, C6, C7, C8, C9 | 0805 | 10 | 100nF | C49678
C13, C16 | 0805 | 2 | 1uF | C28323
C3, C4 | 0805 | 2 | 15pF | C63339
D1 | 0805 | 1 | LED | C2297
J1 | PinSocket_1x03_P2.54mm_Vertical | 1 | Conn_01x03_Pin
R1, R12, R19, R2, R20, R6 | 0805 | 6 | 1k Ohm | C17513
R10, R11 | 0805 | 2 | 27.4 Ohm | C17561
R13 | 0805 | 1 | 300 Ohm | C17617
R14, R18, R3, R4, R5, R7, R8, R9 | 0805 | 8 | 1k Ohm | C17513
R15, R21 | 0805 | 2 | 5.1k Ohm | C27834
R17 | 0805 | 1 | 10k Ohm | C17414
SW1, SW10, SW11, SW12, SW13, SW14, SW2, SW3, SW4, SW5, SW6, SW7, SW8, SW9 | TS-1088-AR02016 | 14 | SW_Push | C720477
U1 | QFN-56-1EP_7x7mm_P0.4mm_EP3.2x3.2mm | 1 | RP2040 | C2040
U3 | SOT-223-3_TabPin2 | 1 | AMS1117-3.3 | C6186
U4 | SOIC127P790X216-8N | 1 | W25Q128JVS | C97521
USB1 | C3039316_USB-SMD_TC-002_1 | 1 | TC-002 | C3039316
Y1 | Crystal_SMD_Abracon_ABM8G-4Pin_3.2x2.5mm | 1 | Crystal_GND24 | C20625731

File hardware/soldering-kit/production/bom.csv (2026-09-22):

Designator | Footprint | Quantity | Value | LCSC Part #
BAT1 | BS-02-A1AJ010 | 1 | CR2032 | C5239862
C1 | C_Disc_D5.0mm_W2.5mm_P5.00mm | 1 | 1u
C2 | C_Disc_D5.0mm_W2.5mm_P5.00mm | 1 | 10n
C3 | C_Disc_D5.0mm_W2.5mm_P5.00mm | 1 | 100n
D1, D2, D3, D4 | LED_D4.0mm | 4 | LED
R1 | R_Axial_DIN0207_L6.3mm_D2.5mm_P10.16mm_Horizontal | 1 | 10k
R2, R3, R4, R5 | R_Axial_DIN0207_L6.3mm_D2.5mm_P10.16mm_Horizontal | 4 | 470R
RV1 | Potentiometer_Bourns_3296W_Vertical | 1 | 500k
U1 | DIP-8_W7.62mm | 1 | TLC555P
U2 | DIP-16_W7.62mm | 1 | CD4017BE

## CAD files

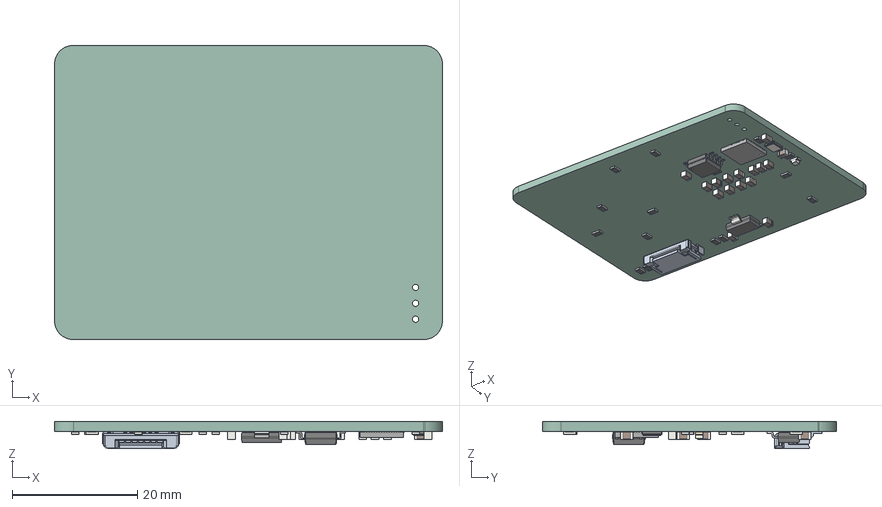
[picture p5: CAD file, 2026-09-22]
hardware/badge/PhoneController.step
62.0 x 47.0 x 4.35 mm
R_0805_2012Metric x 15
C_0805_2012Metric x 16
Crystal_SMD_Abracon_ABM8G-4Pin_3.2x2.5mm
SOT_223
QFN_56_1EP_7x7mm_P04mm_EP32x32mm
LED_0805_2012Metric
SOIC_8_5275x5275mm_P127mm
PhoneController_PCB

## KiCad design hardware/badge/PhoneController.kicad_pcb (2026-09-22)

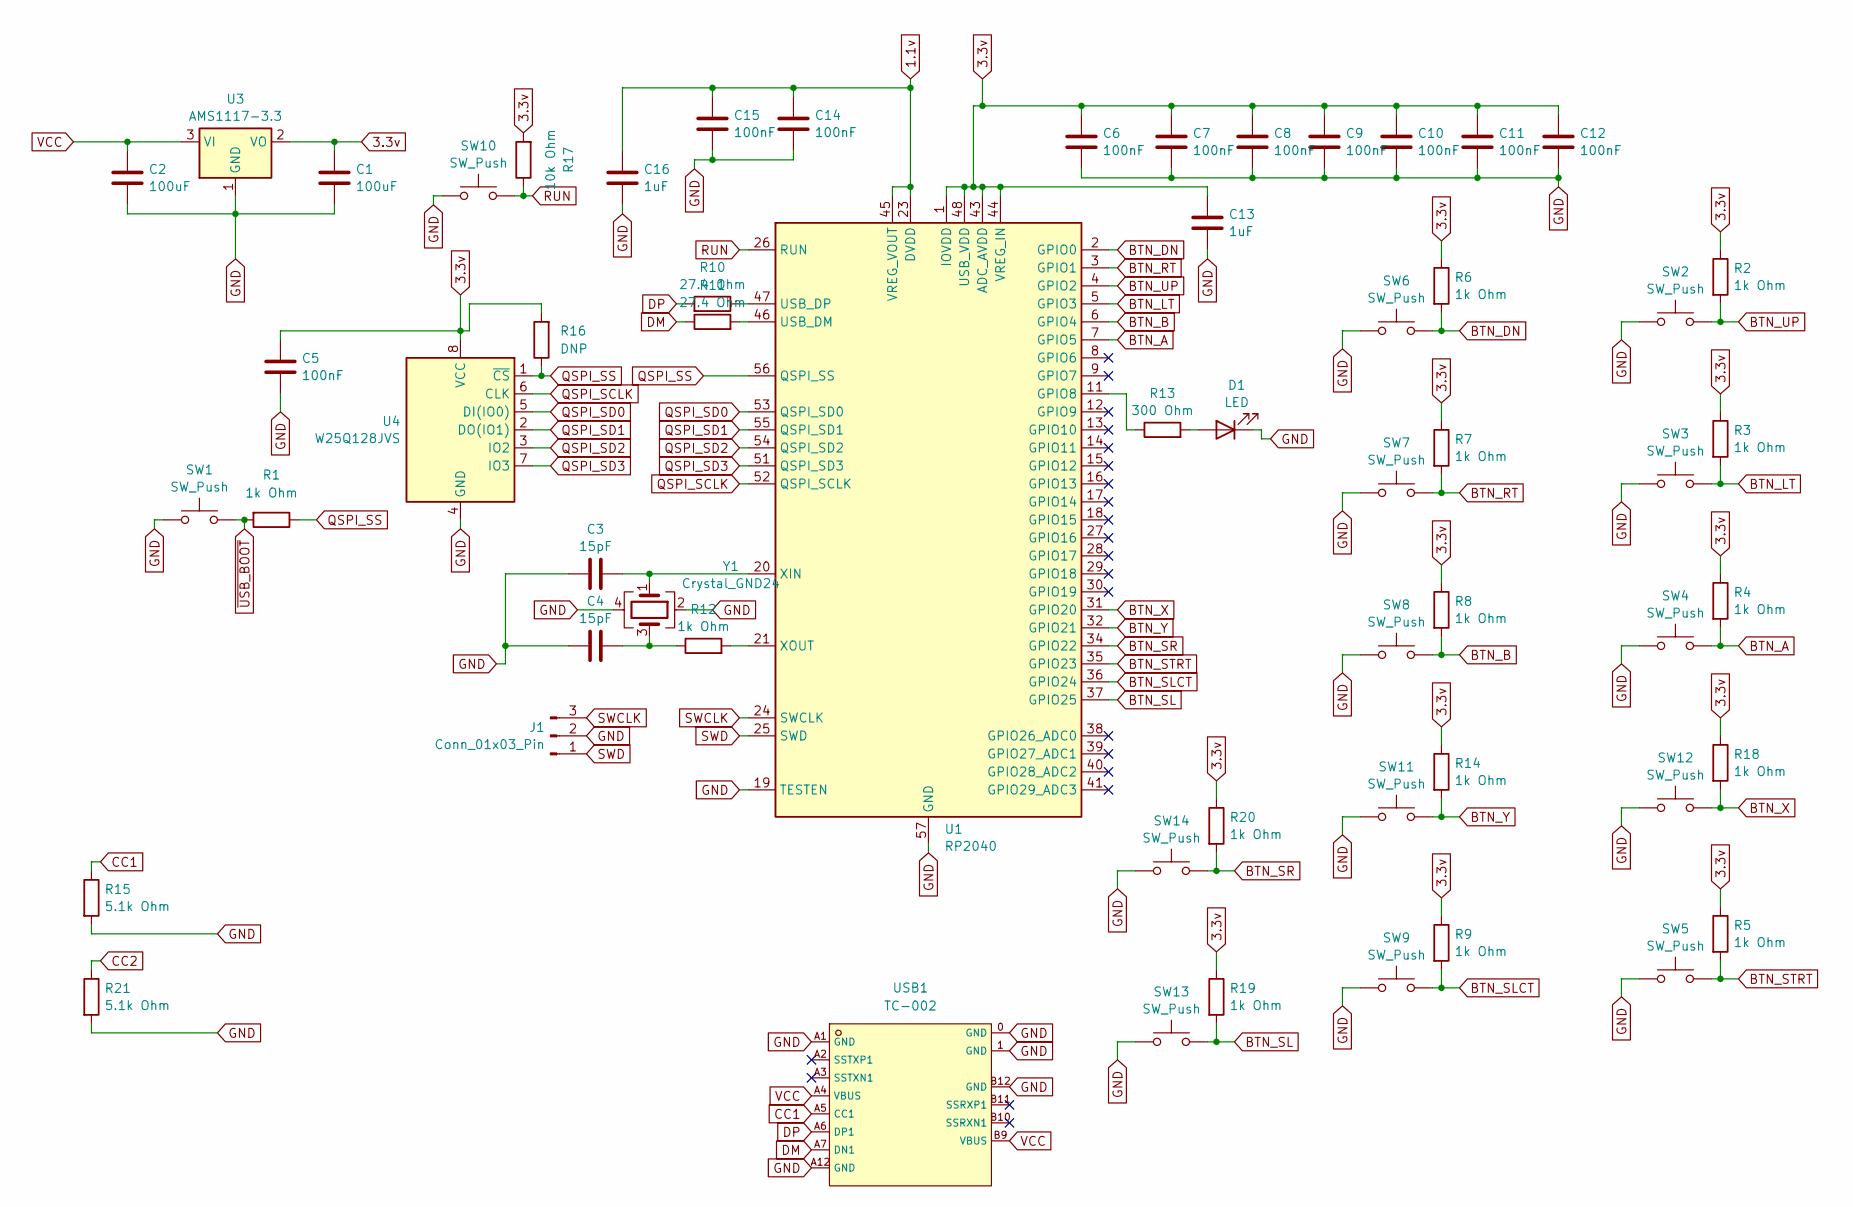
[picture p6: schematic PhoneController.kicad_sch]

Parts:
C1, C2: 100uF; C_1206_3216Metric_Pad1.33x1.80mm_HandSolder
C3, C4: 15pF; C_0805_2012Metric_Pad1.18x1.45mm_HandSolder
C5, C6, C7, C8, C9, C10, C11, C12, C14, C15: 100nF; C_0805_2012Metric_Pad1.18x1.45mm_HandSolder
C13, C16: 1uF; C_0805_2012Metric_Pad1.18x1.45mm_HandSolder
D1: LED; LED_0805_2012Metric_Pad1.15x1.40mm_HandSolder
J1: Conn_01x03_Pin; PinSocket_1x03_P2.54mm_Vertical
R1, R2, R3, R4, R5, R6, R7, R8, R9, R12, R14, R18, R19, R20: 1k Ohm; R_0805_2012Metric_Pad1.20x1.40mm_HandSolder
R10, R11: 27.4 Ohm; R_0805_2012Metric_Pad1.20x1.40mm_HandSolder
R13: 300 Ohm; R_0805_2012Metric_Pad1.20x1.40mm_HandSolder
R15, R21: 5.1k Ohm; R_0805_2012Metric_Pad1.20x1.40mm_HandSolder
R16: DNP; R_0805_2012Metric_Pad1.20x1.40mm_HandSolder
R17: 10k Ohm; R_0805_2012Metric_Pad1.20x1.40mm_HandSolder
SW1, SW2, SW3, SW4, SW5, SW6, SW7, SW8, SW9, SW10, SW11, SW12, SW13, SW14: SW_Push; TS-1088-AR02016
U1: RP2040; QFN-56-1EP_7x7mm_P0.4mm_EP3.2x3.2mm
U3: AMS1117-3.3; SOT-223-3_TabPin2
U4: W25Q128JVS; SOIC127P790X216-8N
USB1: TC-002; C3039316_USB-SMD_TC-002_1; LCSC C3039316
Y1: Crystal_GND24; Crystal_SMD_Abracon_ABM8G-4Pin_3.2x2.5mm

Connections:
1.1v: C14.2, C15.2, C16.2, U1.23 (DVDD), U1.45 (VREG_VOUT), U1.50 (DVDD)
3.3v: C1.1, C5.2, C6.2, C7.2, C8.2, C9.2, C10.2, C11.2, C12.2, C13.2, R2.1, R3.1, R4.1, R5.1, R6.1, R7.1, R8.1, R9.1, R14.1, R16.2, R17.2, R18.1, R19.1, R20.1, U1.1 (IOVDD), U1.10 (IOVDD), U1.22 (IOVDD), U1.33 (IOVDD), U1.42 (IOVDD), U1.43 (ADC_AVDD), U1.44 (VREG_IN), U1.48 (USB_VDD), U1.49 (IOVDD), U3.2 (VO), U4.8 (VCC)
BTN_A: R4.2, SW4.2, U1.7 (GPIO5)
BTN_B: R8.2, SW8.2, U1.6 (GPIO4)
BTN_DN: R6.2, SW6.2, U1.2 (GPIO0)
BTN_LT: R3.2, SW3.2, U1.5 (GPIO3)
BTN_RT: R7.2, SW7.2, U1.3 (GPIO1)
BTN_SL: R19.2, SW13.2, U1.37 (GPIO25)
BTN_SLCT: R9.2, SW9.2, U1.36 (GPIO24)
BTN_SR: R20.2, SW14.2, U1.34 (GPIO22)
BTN_STRT: R5.2, SW5.2, U1.35 (GPIO23)
BTN_UP: R2.2, SW2.2, U1.4 (GPIO2)
BTN_X: R18.2, SW12.2, U1.31 (GPIO20)
BTN_Y: R14.2, SW11.2, U1.32 (GPIO21)
CC1: R15.1, USB1.A5 (CC1)
CC2: R21.1
DM: R11.1, USB1.A7 (DN1)
DP: R10.2, USB1.A6 (DP1)
GND: C1.2, C2.2, C3.1, C4.1, C5.1, C6.1, C7.1, C8.1, C9.1, C10.1, C11.1, C12.1, C13.1, C14.1, C15.1, C16.1, D1.1 (K), J1.2, R15.2, R21.2, SW1.1, SW2.1, SW3.1, SW4.1, SW5.1, SW6.1, SW7.1, SW8.1, SW9.1, SW10.1, SW11.1, SW12.1, SW13.1, SW14.1, U1.19 (TESTEN), U1.57 (GND), U3.1 (GND), U4.4 (GND), USB1.0 (GND), USB1.1 (GND), USB1.A1 (GND), USB1.A12 (GND), USB1.B12 (GND), Y1.2, Y1.4
unnamed: C4.2, R12.1, Y1.3
unnamed: D1.2 (A), R13.2
unnamed: R13.1, U1.11 (GPIO8)
unnamed: R11.2, U1.46 (USB_DM)
unnamed: R10.1, U1.47 (USB_DP)
unnamed: C3.2, U1.20 (XIN), Y1.1
unnamed: R12.2, U1.21 (XOUT)
QSPI_SCLK: U1.52 (QSPI_SCLK), U4.6 (CLK)
QSPI_SD0: U1.53 (QSPI_SD0), U4.5 (DI(IO0))
QSPI_SD1: U1.55 (QSPI_SD1), U4.2 (DO(IO1))
QSPI_SD2: U1.54 (QSPI_SD2), U4.3 (IO2)
QSPI_SD3: U1.51 (QSPI_SD3), U4.7 (IO3)
QSPI_SS: R1.1, R16.1, U1.56 (QSPI_SS), U4.1 (~CS)
RUN: R17.1, SW10.2, U1.26 (RUN)
SWCLK: J1.3, U1.24 (SWCLK)
SWD: J1.1, U1.25 (SWD)
VCC: C2.1, U3.3 (VI), USB1.A4 (VBUS), USB1.B9 (VBUS)
~USB_BOOT: R1.2, SW1.2

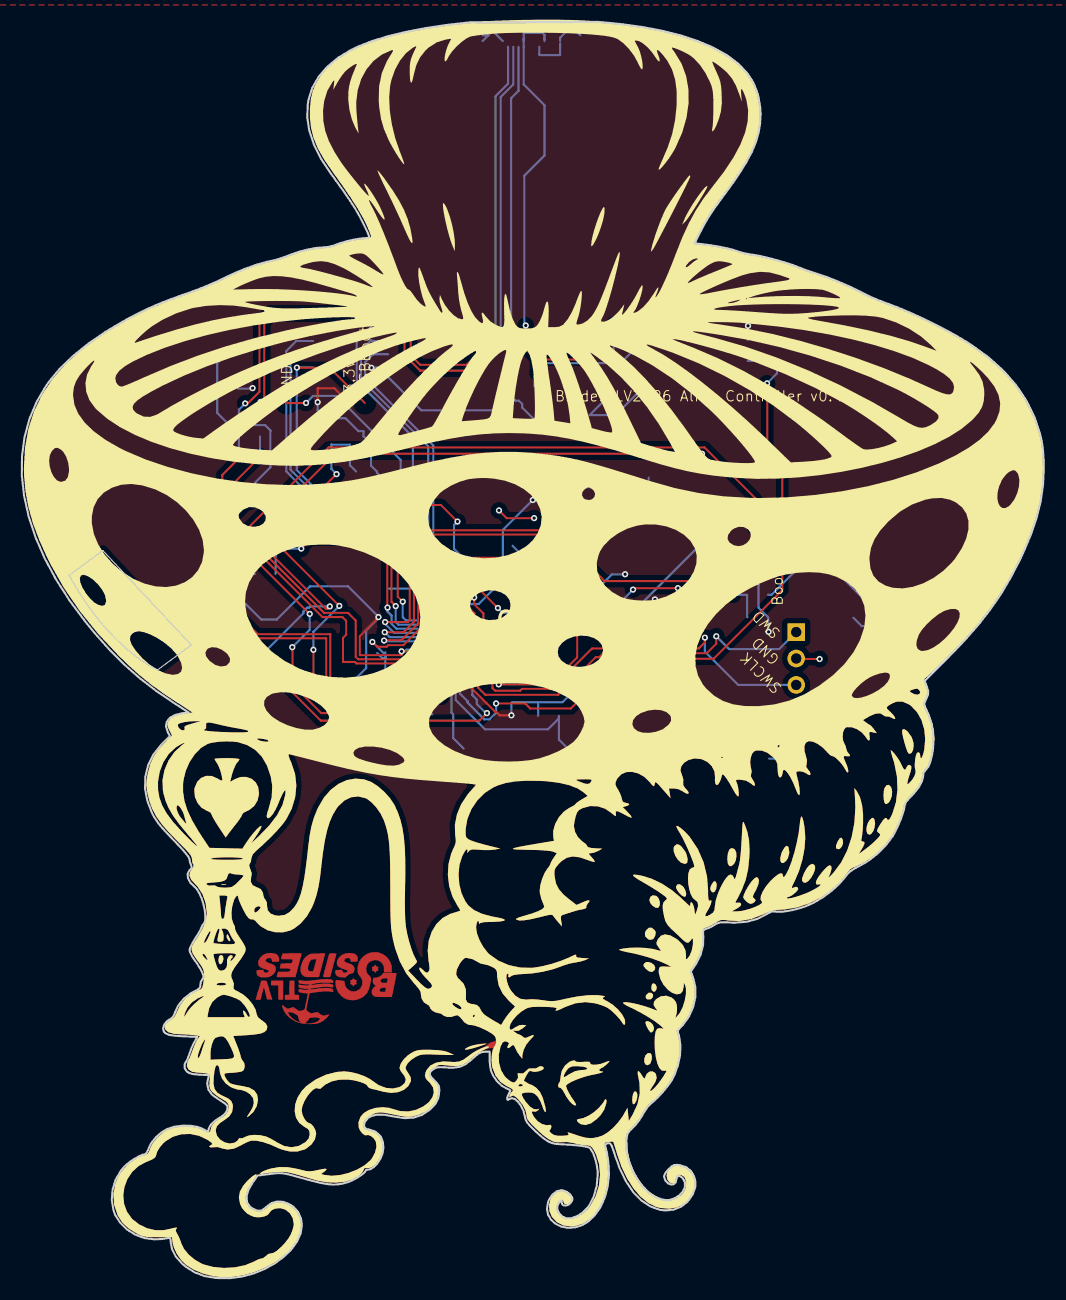
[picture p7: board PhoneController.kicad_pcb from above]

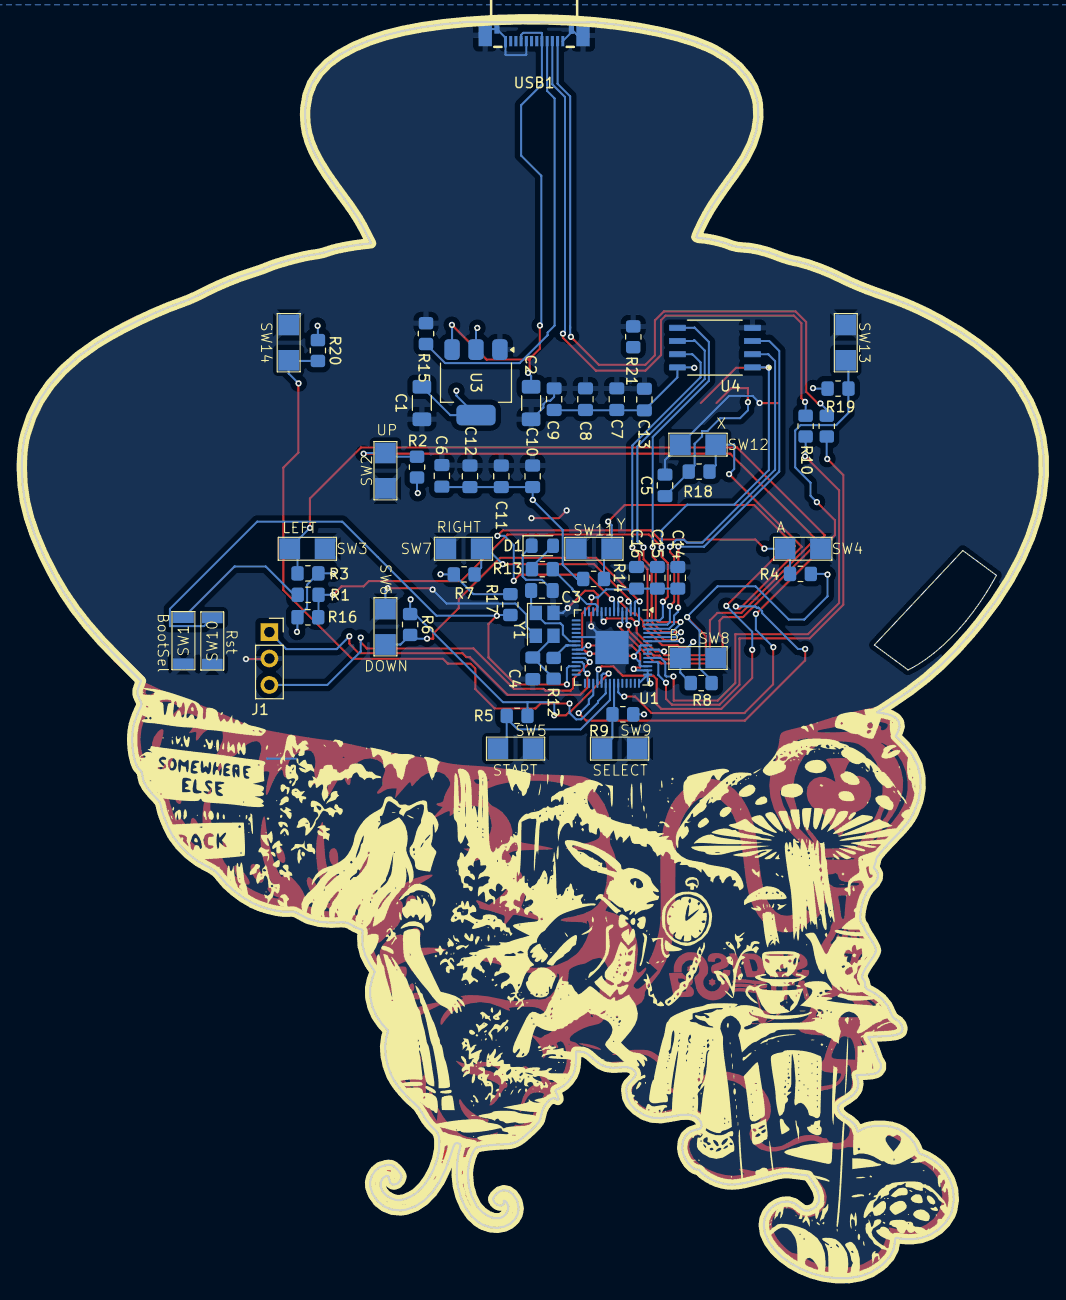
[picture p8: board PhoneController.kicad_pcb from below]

Board: 2 copper layers, 98.2 x 120.7 mm, 58 parts (58 on the bottom side), 36 nets.

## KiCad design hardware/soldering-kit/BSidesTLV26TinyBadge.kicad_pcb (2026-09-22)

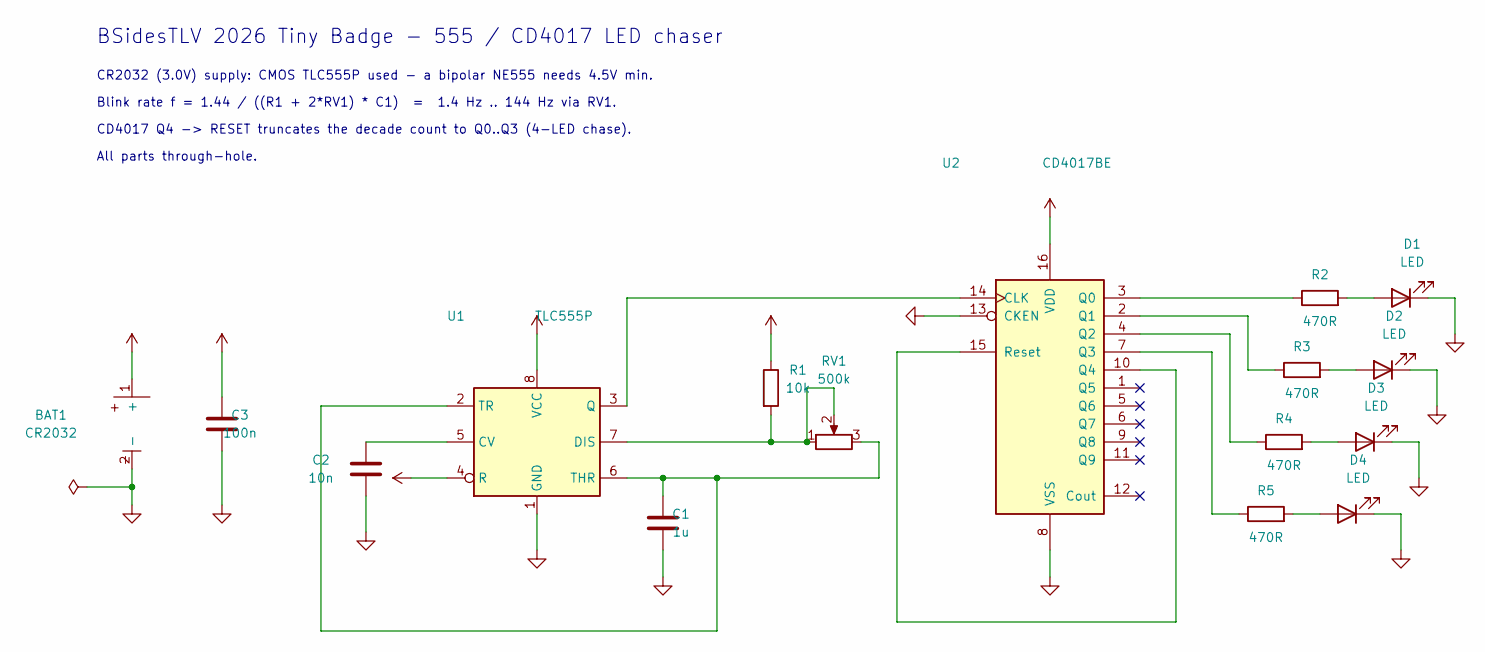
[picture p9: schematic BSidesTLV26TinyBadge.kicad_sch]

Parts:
BAT1: CR2032; BS-02-A1AJ010; MPN C5239862
C1: 1u; C_Disc_D5.0mm_W2.5mm_P5.00mm
C2: 10n; C_Disc_D5.0mm_W2.5mm_P5.00mm
C3: 100n; C_Disc_D5.0mm_W2.5mm_P5.00mm
D1, D2, D3, D4: LED; LED_D4.0mm
R1: 10k; R_Axial_DIN0207_L6.3mm_D2.5mm_P10.16mm_Horizontal
R2, R3, R4, R5: 470R; R_Axial_DIN0207_L6.3mm_D2.5mm_P10.16mm_Horizontal
RV1: 500k; Potentiometer_Bourns_3296W_Vertical
U1: TLC555P; DIP-8_W7.62mm
U2: CD4017BE; DIP-16_W7.62mm

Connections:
GND: BAT1.2 (-), C1.2, C2.2, C3.2, D1.1 (K), D2.1 (K), D3.1 (K), D4.1 (K), U1.1 (GND), U2.8 (VSS), U2.13 (CKEN)
unnamed: D1.2 (A), R2.2
unnamed: D2.2 (A), R3.2
unnamed: D3.2 (A), R4.2
unnamed: D4.2 (A), R5.2
unnamed: C2.1, U1.5 (CV)
unnamed: R1.2, RV1.1, RV1.2, U1.7 (DIS)
unnamed: U1.3 (Q), U2.14 (CLK)
unnamed: C1.1, RV1.3, U1.2 (TR), U1.6 (THR)
unnamed: R2.1, U2.3 (Q0)
unnamed: R3.1, U2.2 (Q1)
unnamed: R4.1, U2.4 (Q2)
unnamed: R5.1, U2.7 (Q3)
unnamed: U2.10 (Q4), U2.15 (Reset)
VCC: BAT1.1 (+), C3.1, R1.1, U1.4 (R), U1.8 (VCC), U2.16 (VDD)

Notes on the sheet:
CR2032 (3.0V) supply: CMOS TLC555P used - a bipolar NE555 needs 4.5V min.
BSidesTLV 2026 Tiny Badge - 555 / CD4017 LED chaser
All parts through-hole.
CD4017 Q4 -> RESET truncates the decade count to Q0..Q3 (4-LED chase).
Blink rate f = 1.44 / ((R1 + 2*RV1) * C1) = 1.4 Hz .. 144 Hz via RV1.

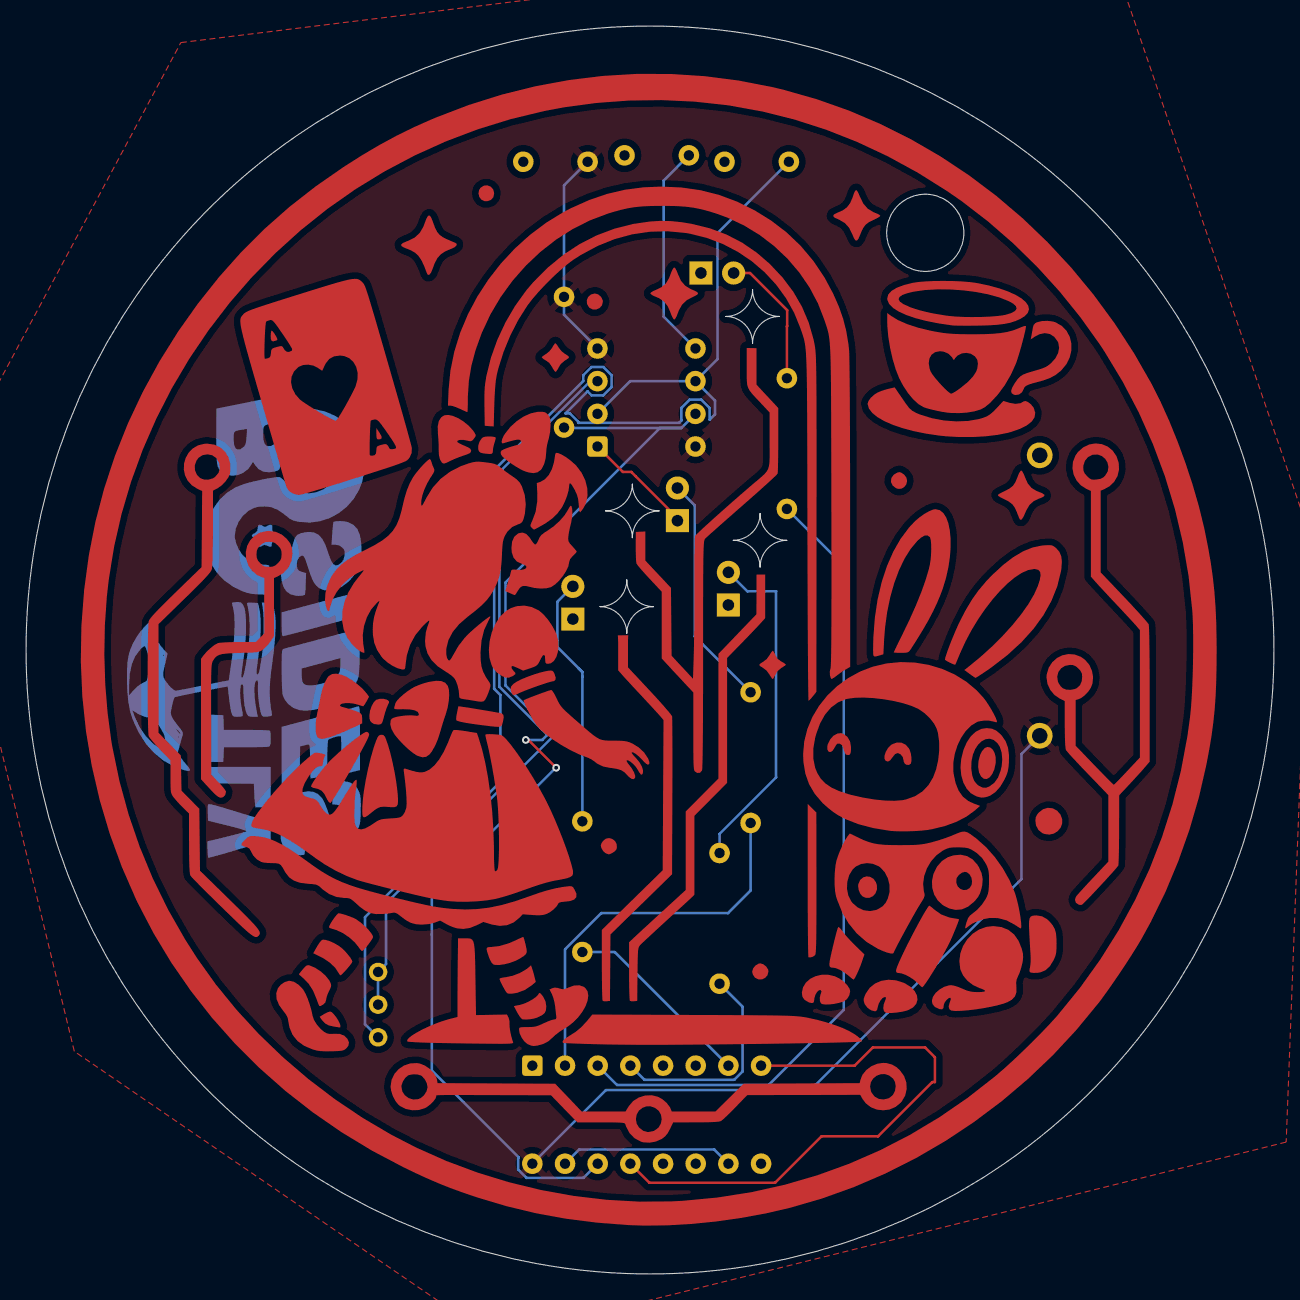
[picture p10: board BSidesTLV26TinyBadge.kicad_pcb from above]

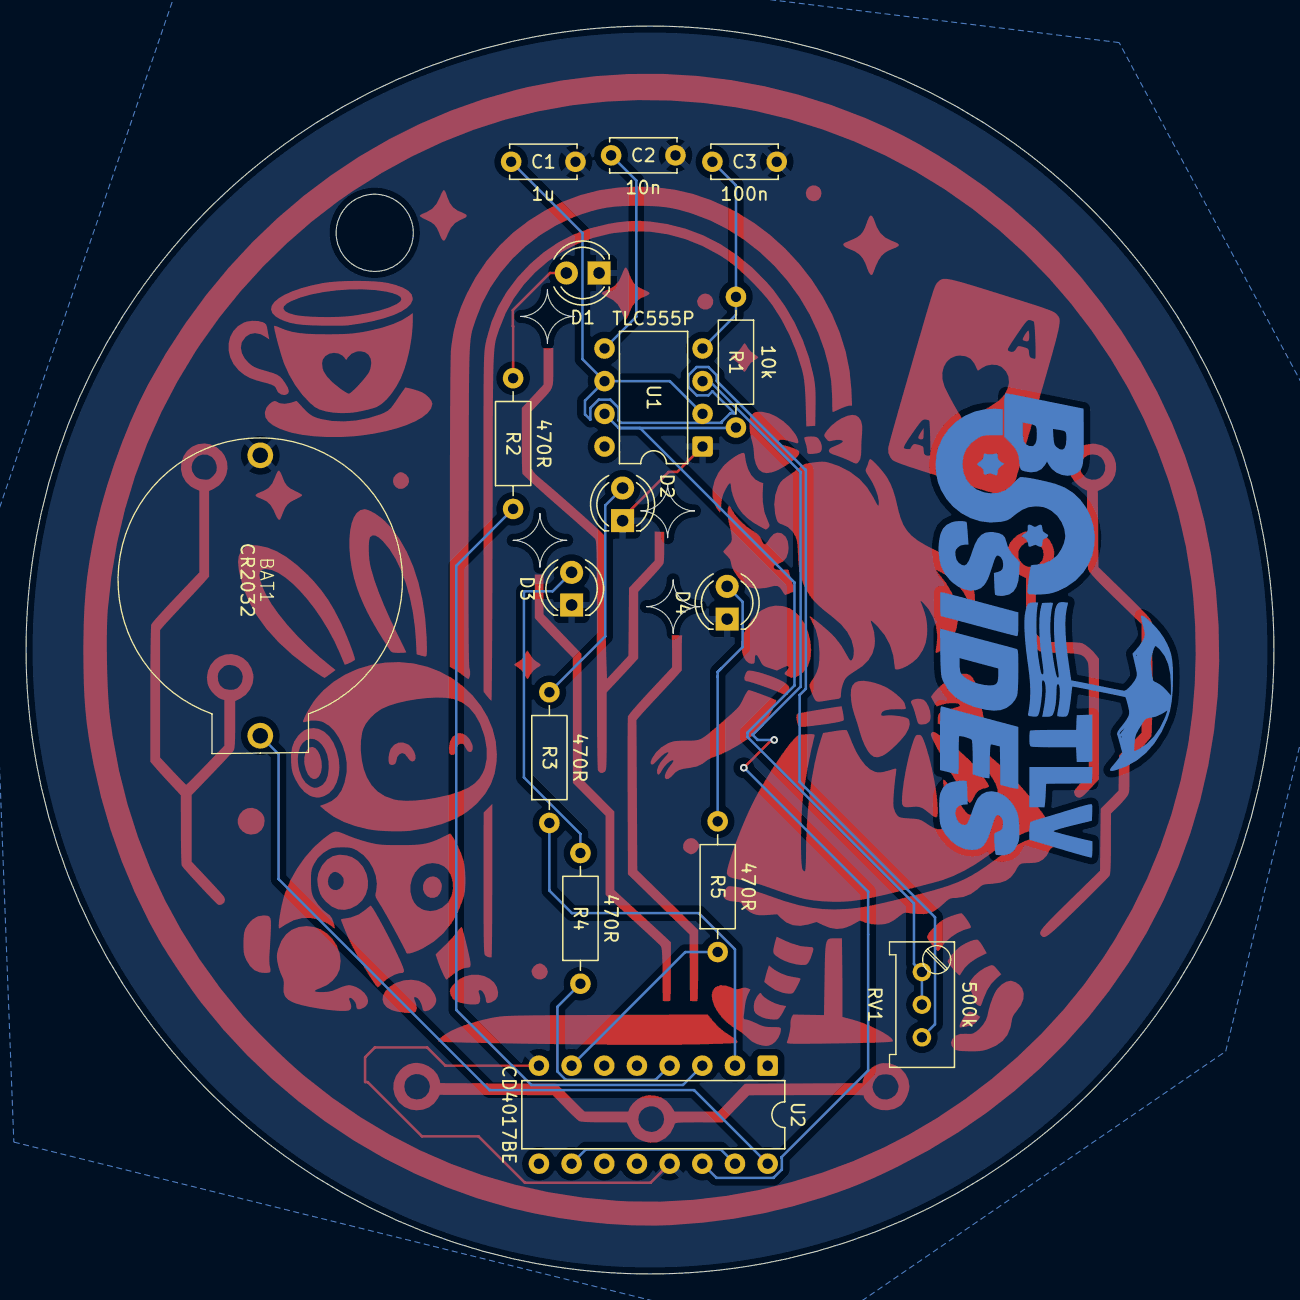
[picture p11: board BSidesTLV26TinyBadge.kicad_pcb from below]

Board: 2 copper layers, 97.0 x 97.0 mm, 16 parts (16 on the bottom side), 15 nets.

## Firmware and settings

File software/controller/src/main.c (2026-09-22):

/*
 * BSidesTLV2026 Alice Controller - a USB HID game controller for the Raspberry Pi Pico.
 *
 * Mimics a Game Boy Color button layout (D-pad + A/B + START/SELECT) and
 * presents itself to a host as a wired DualShock 4.
 *
 * A generic HID gamepad works on Android, PC and Linux but is invisible on
 * iOS/iPadOS: Apple's GameController framework only attaches to controllers
 * it recognises by USB VID/PID. Speaking the DualShock 4's identity and
 * input report gets an iPhone to bind a real controller profile, and the
 * same descriptor is understood everywhere else too.
 *
 * Wiring (all buttons are active-low, i.e. wired to GND, using the internal
 * pull-ups - external pull-ups are also fine):
 *
 *   GPIO0  -> D-pad DOWN
 *   GPIO1  -> D-pad RIGHT
 *   GPIO2  -> D-pad UP
 *   GPIO3  -> D-pad LEFT
 *   GPIO4  -> B
 *   GPIO5  -> A
 *   GPIO20 -> X
 *   GPIO21 -> Y
 *   GPIO22 -> SR (right shoulder)
 *   GPIO25 -> SL (left shoulder)
 *   GPIO23 -> START
 *   GPIO24 -> SELECT
 *   GPIO8  -> status LED (active-high)
 */

#include <string.h>

#include "pico/stdlib.h"
#include "tusb.h"

#include "usb_descriptors.h"
#include "ds4.h"

//--------------------------------------------------------------------+
// Pin configuration
//--------------------------------------------------------------------+

#define PIN_DOWN    0u
#define PIN_RIGHT   1u
#define PIN_UP      2u
#define PIN_LEFT    3u
#define PIN_B       4u
#define PIN_A       5u
#define PIN_X       20u
#define PIN_Y       21u
#define PIN_SR      22u
#define PIN_SL      25u
#define PIN_START   23u
#define PIN_SELECT  24u

#define PIN_LED     8u

// All face/dpad buttons used by the controller, so we can init them in a loop.
static const uint8_t k_button_pins[] = {
  PIN_DOWN, PIN_RIGHT, PIN_UP, PIN_LEFT,
  PIN_B, PIN_A, PIN_X, PIN_Y, PIN_SR, PIN_SL, PIN_START, PIN_SELECT,
};

// Buttons are active-low (pressed == logic 0 thanks to the pull-up).
static inline bool button_pressed(uint8_t pin)
{
  return !gpio_get(pin);
}

//--------------------------------------------------------------------+
// Status LED
//--------------------------------------------------------------------+

// Blink intervals (ms) signalling the USB connection state.
enum {
  BLINK_NOT_MOUNTED = 250,
  BLINK_SUSPENDED   = 1000,
};

// 0 means "don't blink, let the application drive the LED directly".
static uint32_t blink_interval_ms = BLINK_NOT_MOUNTED;

static inline uint32_t now_ms(void)
{
  return to_ms_since_boot(get_absolute_time());
}

static void board_setup(void)
{
  for ( size_t i = 0; i < sizeof(k_button_pins) / sizeof(k_button_pins[0]); i++ )
  {
    uint8_t pin = k_button_pins[i];
    gpio_init(pin);
    gpio_set_dir(pin, GPIO_IN);
    // gpio_pull_up(pin);
  }

  gpio_init(PIN_LED);
  gpio_set_dir(PIN_LED, GPIO_OUT);
  gpio_put(PIN_LED, 0);
}

//--------------------------------------------------------------------+
// USB device callbacks
//--------------------------------------------------------------------+

void tud_mount_cb(void)
{
  blink_interval_ms = 0; // application now controls the LED
}

void tud_umount_cb(void)
{
  blink_interval_ms = BLINK_NOT_MOUNTED;
}

void tud_suspend_cb(bool remote_wakeup_en)
{
  (void) remote_wakeup_en;
  blink_interval_ms = BLINK_SUSPENDED;
}

void tud_resume_cb(void)
{
  blink_interval_ms = tud_mounted() ? 0 : BLINK_NOT_MOUNTED;
}

//--------------------------------------------------------------------+
// DualShock 4 input report
//--------------------------------------------------------------------+

static uint8_t compute_hat(bool up, bool down, bool left, bool right)
{
  // Opposite directions cancel out so we never report an impossible diagonal.
  if (up && down)    { up = down = false; }
  if (left && right) { left = right = false; }

  if (up && right)   return DS4_HAT_NE;
  if (up && left)    return DS4_HAT_NW;
  if (down && right) return DS4_HAT_SE;
  if (down && left)  return DS4_HAT_SW;
  if (up)            return DS4_HAT_N;
  if (down)          return DS4_HAT_S;
  if (left)          return DS4_HAT_W;
  if (right)         return DS4_HAT_E;
  return DS4_HAT_NONE;
}

static void build_report(ds4_input_report_t *report, uint8_t counter, uint16_t timestamp)
{
  memset(report, 0, sizeof(*report));

  // No analog sticks on this board: report both centred and both triggers released.
  report->lx = report->ly = DS4_STICK_CENTER;
  report->rx = report->ry = DS4_STICK_CENTER;

  report->buttons0 = compute_hat(
      button_pressed(PIN_UP),
      button_pressed(PIN_DOWN),
      button_pressed(PIN_LEFT),
      button_pressed(PIN_RIGHT));

  // Game Boy face buttons map onto the DualShock diamond in the same positions.
  if (button_pressed(PIN_A))      report->buttons0 |= DS4_BTN_CROSS;
  if (button_pressed(PIN_B))      report->buttons0 |= DS4_BTN_CIRCLE;
  if (button_pressed(PIN_X))      report->buttons0 |= DS4_BTN_SQUARE;
  if (button_pressed(PIN_Y))      report->buttons0 |= DS4_BTN_TRIANGLE;

  if (button_pressed(PIN_SL))     report->buttons1 |= DS4_BTN_L1;
  if (button_pressed(PIN_SR))     report->buttons1 |= DS4_BTN_R1;
  if (button_pressed(PIN_START))  report->buttons1 |= DS4_BTN_OPTIONS;
  if (button_pressed(PIN_SELECT)) report->buttons1 |= DS4_BTN_SHARE;

  // The low two bits of buttons2 are PS and touchpad-click; the counter lives
  // in the upper six and must advance on every report.
  report->buttons2 = (uint8_t) (counter << 2);

  report->timestamp   = timestamp;
  report->status      = DS4_STATUS_FULL;
  report->touch_count = 0;
}

// Poll buttons and stream a report to the host. Unlike a generic HID gamepad
// we send on every interval rather than only on change: the real controller
// streams continuously, and the report counter has to keep moving for drivers
// that use it to detect a stalled device.
static void hid_task(void)
{
  const uint32_t poll_interval_ms = 5;
  static uint32_t last_poll_ms = 0;
  static uint8_t counter = 0;
  static uint16_t timestamp = 0;

  if ( now_ms() - last_poll_ms < poll_interval_ms ) return;
  last_poll_ms = now_ms();

  ds4_input_report_t report;
  build_report(&report, counter, timestamp);

  // Wake the host if we are suspended and the user presses something.
  if ( tud_suspended() )
  {
    if ( (report.buttons0 & 0xF0) || report.buttons1 ||
         (report.buttons0 & 0x0F) != DS4_HAT_NONE )
    {
      tud_remote_wakeup();
    }
    return;
  }

  if ( !tud_hid_ready() ) return;

  if ( tud_hid_report(DS4_REPORT_ID_INPUT, &report, sizeof(report)) )
  {
    counter = (uint8_t) ((counter + 1) & 0x3F);
    // 5.33 us ticks, so a 5 ms interval advances the stamp by ~938.
    timestamp = (uint16_t) (timestamp + 938);
  }
}

//--------------------------------------------------------------------+
// LED feedback
//--------------------------------------------------------------------+

static void led_task(void)
{
  // When mounted (blink_interval_ms == 0) light the LED while any input is
  // active, giving immediate tactile feedback. Otherwise blink to signal the
  // current USB state.
  if ( blink_interval_ms == 0 )
  {
    bool any = false;

    for ( size_t i = 0; i < sizeof(k_button_pins) / sizeof(k_button_pins[0]); i++ )
    {
      if ( button_pressed(k_button_pins[i]) ) { /* any = true; */  break; }
    }

    gpio_put(PIN_LED, any);
    return;
  }

  static uint32_t last_toggle_ms = 0;
  static bool led_on = false;

  if ( now_ms() - last_toggle_ms < blink_interval_ms ) return;
  last_toggle_ms = now_ms();

  led_on = !led_on;
  gpio_put(PIN_LED, led_on);
}

//--------------------------------------------------------------------+
// Main
//--------------------------------------------------------------------+

int main(void)
{
  board_setup();

  tud_init(BOARD_TUD_RHPORT);

  while (1)
  {
    tud_task();   // service the USB device stack
    hid_task();   // read buttons and send reports
    led_task();   // status / activity LED
  }
}

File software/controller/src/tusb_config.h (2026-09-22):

#ifndef _TUSB_CONFIG_H_
#define _TUSB_CONFIG_H_

#ifdef __cplusplus
extern "C" {
#endif

//--------------------------------------------------------------------+
// Board / port configuration
//--------------------------------------------------------------------+

// RP2040/RP2350 on-chip full-speed USB controller lives on root hub port 0.
#ifndef BOARD_TUD_RHPORT
#define BOARD_TUD_RHPORT      0
#endif

#ifndef BOARD_TUD_MAX_SPEED
#define BOARD_TUD_MAX_SPEED   OPT_MODE_FULL_SPEED
#endif

//--------------------------------------------------------------------+
// Common configuration
//--------------------------------------------------------------------+

#ifndef CFG_TUSB_MCU
#error CFG_TUSB_MCU must be defined (provided by the Pico SDK)
#endif

#ifndef CFG_TUSB_OS
#define CFG_TUSB_OS           OPT_OS_NONE
#endif

#ifndef CFG_TUSB_DEBUG
#define CFG_TUSB_DEBUG        0
#endif

#ifndef CFG_TUSB_MEM_SECTION
#define CFG_TUSB_MEM_SECTION
#endif

#ifndef CFG_TUSB_MEM_ALIGN
#define CFG_TUSB_MEM_ALIGN    __attribute__ ((aligned(4)))
#endif

//--------------------------------------------------------------------+
// Device configuration
//--------------------------------------------------------------------+

#define CFG_TUD_ENABLED       1
#define CFG_TUD_MAX_SPEED     BOARD_TUD_MAX_SPEED

#ifndef CFG_TUD_ENDPOINT0_SIZE
#define CFG_TUD_ENDPOINT0_SIZE    64
#endif

// Enabled classes: a single HID interface (the gamepad).
#define CFG_TUD_HID               1
#define CFG_TUD_CDC               0
#define CFG_TUD_MSC               0
#define CFG_TUD_MIDI              0
#define CFG_TUD_VENDOR            0

// HID buffer size: the DualShock 4 uses 64-byte interrupt endpoints, and the
// largest feature report it answers is also 64 bytes.
#define CFG_TUD_HID_EP_BUFSIZE    64

#ifdef __cplusplus
}
#endif

#endif /* _TUSB_CONFIG_H_ */

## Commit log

2026-09-22 Organize the badge repo: hardware/ + software/, licences, docs
    The tree was two loose drops - a KiCad dumping ground under hw/ and a nested
    git repo for the challenge. Both are now one repo with two halves that match
    how the badge is actually used: boards in hardware/, the online challenge that
    runs on them in software/.
    Hardware, three KiCad 9 projects, one directory each, doubled folder nesting
    flattened:
    hardware/badge/ the PCB-art badge, with its source graphics
    hardware/soldering-kit/ the TLC555 + CD4017 workshop kit
    hardware/controller/ BSidesTLV2026 Alice Controller v0.4, the RP2040 controller
    Loose gerbers moved into controller/gerbers/. Removed ~40MB of KiCad rol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
    [BSidesTLV26Badge.kicad_pcb, BSidesTLV26Badge.kicad_sch, BSidesTLV26TinyBadge.kicad_pcb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]
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2026-09-22 Add the badge firmware as software/controller
    The board had no firmware in the repo, so nobody could build what the badge
    actually runs. Copied in from the upstream project - which is left in place and
    unmodified - as software/controller/, with the upstream target renamed to controller
    throughout the build.
    The rename only touches CMake: project(), the executable target and the four
    commands that name it, so the build now produces build/controller.uf2. It does
    not touch USB identity - the descriptors report Sony's VID/PID 054C:09CC and
    the strings "Sony Interactive Entertainment" / "Wireless Controller", which is
    the whole point of the design. iOS only binds controllers it recognizes by
    VID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
    [PhoneControllerCaseV0.3 - BackPlate.stl, PhoneControllerCaseV0.3 - BtnA.stl, PhoneControllerCaseV0.3 - BtnB.stl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]
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2026-09-22 Revert the CC-pin analysis; leave hardware commentary to the author
    I had rewritten the USB-C note from my own reading of the netlist and added a
    "Known issue" section to hardware/README.md. Both are out. The original note is
    restored verbatim from the upstream project, and hardware/README.md carries no
    claim about CC pins.
    No hardware design file was ever modified by any commit in this branch - the
    history shows only adds from moving files into the repo and the two deletions
    that were asked for. hardware/badge/'s .kicad_pcb, .kicad_sch and .kicad_pro are
    still byte-identical to the copy at ~/kicad/PhoneController/.
    The restored note refers to hw/usb/PhoneControllerUSB.kicad_sch, which is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
2026-09-22 Serve the site from the repo root
    GitHub Pages serves a repository root or a /docs folder; software/site/ was
    neither, so publishing needed the workflow to reach into a subdirectory. Moved
    index.html, styles.css, src/, stages/, assets/ and .nojekyll up to the root,
    where a branch-based Pages source would also find them. package.json and
    serve.sh came up with them, since both exist to serve and check the site.
    software/ is now strictly the things that produce the site and are never
    served: tools/, references/, legacy/, docs/ and the controller firmware.
    Tools repointed for the extra level - the Python slicers write ../../assets,
    both verifiers import ../../src and resolve their stage argume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
2026-09-24 Add quick glitch: record / replay with speed, offset and repeat
    The challenge site is getting a glitch range, and its point is that some
    windows cannot be hit by hand. So the firmware grows a layer between the
    buttons and the USB report that records a take of presses with microsecond
    timestamps and replays it on command: a START tap as the trigger the host
    measures from, a wait of `offset`, then the take at `speed`. SELECT is the
    shift key - SL records, SR fires (hold to repeat), UP/DOWN scale the speed
    from 1/4x to 32x, LEFT/RIGHT step the offset by 1 ms with an accelerating
    auto-repeat, B forgets everything. A bare SELECT press is still forwarded
    as a tap on release.
    The engine is plain C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
2026-09-24 Add the glitch range: two practice rooms for the badge's quick glitch
    glitch.html is where the badge gets used as a fault-injection tool. Two
    rooms, each with levels that start inside the human budget and end well
    outside it:
    - The Rabbit's Pocket Watch: a fixed tune of buttons to enter inside a
    window, from 4 presses in 2 s to 12 in 600 ms. The tune is fixed per
    level so a take recorded once on the badge keeps working; the answer to
    the last levels is to record slowly and replay at 4x or 8x.
    - The Looking-Glass Glitch: the Queen's guard runs a routine one line per
    tick and one line is the check that turns Alice away. A pulse on X whose
    rising edge lands on that line skips it; th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
2026-09-25 Add bench tools for bringing the quick glitch up on a badge
    A Bench panel on the range page prints every edge the browser sees, timed
    from the last START, so a fire can be read off as offset and width. For
    the real numbers, tools/hid-trace.py reads the raw DualShock 4 reports
    from /dev/hidraw at the 1 ms report rate and prints edges with microsecond
    stamps, plus a report-rate and counter-gap stat every 5 s.
    Claude-Session: https://claude.ai/code/session_017ZncXHHhPNNrEtFRpgJbfX
2026-09-25 Publish the glitch range branch to Pages, and let the workflow enable Pages
    The fork has never had Pages switched on and the workflow only ran on main,
    so the range was not reachable anywhere. The workflow now enables Pages on
    its first run and also deploys pushes to the development branch; the
    branch entry goes away on merge.
    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
2026-10-06 Flash the badge over USB: flash-badge.py, a SELECT+START chord into the bootloader, Windows build scripts
    The firmware has only ever been checked by the host test and a cross-build;
    getting it onto a board needed a toolchain and a hand on the BootSel button.
    Three things close that:
    - software/tools/flash-badge.py waits for the RPI-RP2 drive, checks the UF2
    is for an RP2040, copies it, waits for the ROM to reboot and confirms the
    controller (054c:09cc) came back. --fetch takes the newest green Firmware
    workflow artifact, so no local toolchain is needed; --status says what is
    plugged in. Standard library, Windows/macOS/Linux.
    - Holding SELECT + START for two seconds calls reset_usb_b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
2026-10-06 Give the glitch range an on-screen pad, and fit the map to a phone
    The range is meant to be opened on the phone the badge is plugged into, and
    a phone has no keyboard: with the badge unplugged there was no way to press
    anything. A <details> fixed to the bottom of the page holds a D-pad, the
    diamond, the shoulders and START/SELECT; each feeds pad.inject() with the
    pointer event's own timestamp as source 'ui', so the Bench shows them and
    tells them apart from the badge. It opens by default on coarse pointers and
    collapses to one line on a desktop. The buttons are sized against the
    viewport so three keys and two gaps per cluster fit a 320 px phone.
    The Looking-Glass room is 432 px wide and use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
2026-10-06 Publish the firmware with the site: pages.yml builds glitch.uf2 and its manifest
    The deploy now cross-builds software/controller through build-uf2.yml and
    stages the result as firmware/glitch.uf2 next to the pages, with
    firmware/index.json saying which commit built it, when, how big and its
    SHA-256 - what flash.html's cards show and check. Pushes that touch the
    firmware redeploy the site too, so the image on offer is never older than
    the page. flash.html joins the staged paths, and the Pages trigger names the
    branch this is being developed on in place of the one that already merged.
2026-10-06 Link the flash page from the stages and the range, and document the browser route
    index.html and glitch.html point at flash.html from their headers, the range's
    chord table says the page does the copy, and the READMEs describe the WebUSB
    route beside flash-badge.py. CLAUDE.md gains the new files, the firmware/
    path the deploy produces, the workflow split, a status row for the flasher
    and the loose end that it has never met a real bootloader; it also stops
    claiming the fork's main mirrors upstream, which stopped being true when the
    glitch labs merged.
2026-10-06 Wait for the range's art to load, not to decode
    glitch.js awaited img.decode() on every sprite before anything ran. In a
    hidden tab Chrome settles those promises only when it next paints a
    frame, so glitch.html opened in the background sat blank until it was
    looked at. Wait for `load` instead; drawImage decodes a 48 px sprite on
    first use in well under a millisecond.
2026-10-06 Give the glitch range four looks: classic, tidy bench, handheld, scope
    On a phone the range page spent a third of the screen on the header and
    the fixed pad, another third on prose, and stacked the level tabs four
    deep. The three new looks are phone-first and share one DOM; the
    differences are CSS in src/glitch.css, keyed on <html data-theme>:
    bench same palette, one range on screen at a time behind a
    Watch / Glass / Bench / ? bar, prose folded under "how it
    works", level chips in a row, the pad a bottom sheet
    handheld the phone is the console: the panel sits in a bezelled
    screen, the mode bar becomes device buttons, the pad is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
2026-10-07 Put the looks behind a picker, and make each look a drop-in file
    The header's select becomes a ◐ chip that opens a sheet of cards, one per
    look, each with a miniature painted in the look's two colours; the ? help
    shows the same cards. Tapping a card switches in place and the choice is
    remembered; "use default" forgets it.
    What the picker lists comes from src/looks/index.json: id, label, blurb,
    swatch, the miniature's shape, whether it is a phone look, and whether
    its pad is part of the body. Each phone look's CSS moves out of
    src/glitch.css into src/looks/<id>.css, loaded through one <link> that
    the head script adds before first paint and the module swaps on a switch
    (the new sheet loads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
2026-10-08 Give the badge a vault: a stage key in the last flash sector, read over report 0xF1 and a SELECT+Y beacon
    The badge becomes the key to the challenge site. vault.c keeps a 32-byte
    stage key and a label in the last 4 KB sector, which no firmware image
    reaches, so it survives reflashing. Two ways out, both pure functions of the
    vault: HID feature report 0xF1, one of the vendor reports the DualShock 4
    descriptor already declares (so the descriptor stays byte-identical and iOS
    keeps binding), and a beacon that spells the same payload on the four stick
    axes while SELECT+Y is held, for browsers that have a Gamepad API but no
    WebHID. Left X is a 50 ms clock, the other axes a nibble each as one of 16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
2026-10-08 Gate the site on the badge and seal stages under its key
    On the published site nothing plays until a badge has shown its vault.
    src/gate.js raises the dialog: Connect over WebHID (feature report 0xF1,
    src/vault.js) or hold SELECT+Y and the page decodes the beacon off the pad's
    own poll, with a bar. src/pad.js carries the policy: every edge has a source
    and the site's Pad passes only 'pad', so the keyboard is never attached, the
    on-screen pad and the Run button are not offered, and inject() returns
    false. A dev host (localhost) keeps every source and no gate; ?gate=1 brings
    the dialog up there. Both stages on index.html are now driven by the badge:
    d-pad, Y waits a tick, START resets, the sta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
2026-10-14 Make the looks a site-wide setting, picked from every page's header
    The four looks were the range page's alone. Now every page carries the
    same chip: src/look-boot.js applies the chosen look before paint (URL,
    then the device's memory under alice.look, then the touch default), and
    src/looks.js builds the picker sheet, swaps the stylesheet and runs the
    mode bar, so a page needs only the chip, data-look-touch on <html> and
    data-mode on its panels. The shared phone block and the picker's styles
    move from src/glitch.css into styles.css; glitch.css keeps what only the
    range reshapes.
    The stages page gets a mode bar of its own in the phone looks - Tea,
    Gauntlet, Walk, Art, ? - and the mode on scr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
2026-10-14 Add a third range: the Caterpillar's Lock, a timing side-channel door
    The Caterpillar's door wants a password and checks it one symbol per tick,
    stopping at the first mismatch, so the time it takes to say no is how many
    symbols were right plus one. START opens a guess, one press per symbol, the
    door checks the moment the last one is in; on the badge that is a take fired
    with START as the trigger, and holding the chord repeats it.
    Three levels. "Who are you?" is the textbook attack by hand: four of four,
    300 ms a tick, no noise. "Keep your temper" adds half a tick of jitter, so a
    guess has to be measured several times and the page keeps every sample of a
    guess together with its median - the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
2026-10-14 Let the badge announce itself by name, and send a nameless controller to the flash page
    The firmware keeps Sony's VID/PID (iOS binds by those) but now carries its
    own string descriptors: "BSidesTLV" / "BSidesTLV 2026 Alice Controller".
    Browsers put the product string in Gamepad.id, so the page can tell a
    badge from a real DualShock 4 - and from a badge still running the stock
    firmware, which keeps Sony's strings. src/pad.js knows the name
    (isBadgeId) and marks the device record, refreshing it when the name in a
    slot changes, as it does when a badge comes back from a flash.
    The gate uses that: its gamepad line says whether the connected controller
    is the badge firmware, and when it is not, s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
2026-10-14 Turn the badge's buttons over when the phone is upside down
    The badge is a grip the phone sits in, so a phone held the other way up
    turns the whole controller over while the screen rights itself. The pad
    now reads the screen's orientation and, in a "secondary" one (or with
    window.orientation at 180), turns every gamepad edge through FLIP:
    UP/DOWN, LEFT/RIGHT, A/Y and B/X swap; the shoulders, START and SELECT
    stay. Keyboard and on-screen edges are never turned. A turn while a
    button is held renames it on the next poll. ?flip=1|0 pins it for
    testing and pad.flip switches it at runtime. Nothing in the firmware
    changes.
2026-10-14 Tell the badge is upside down from gravity, not only from the screen
    An iPhone, and most Android phones, never rotate a portrait page to
    upside down, so screen.orientation stays put and the pad's turn never
    fired. src/tilt.js reads deviceorientation (beta/gamma -> the device's up
    vector; devicemotion's sign is inverted on iOS), takes the OS's own turn
    out, flips past 150 deg and comes back under 30, and holds while the phone
    lies flat. Pad.flipped now follows the screen or gravity, under the
    alice.flip hand switch; iOS's permission call is request().
2026-10-14 A turn-over switch in the looks sheet, and the sensors on every page
    The sheet gets 'turn over: auto / no / yes', remembered as alice.flip, with
    the sensor's reading beside it; 'use default' clears it. initLooks starts
    the tilt on every page, pad or no pad, so the flash and vault pages turn
    too. verify-looks checks the rule, the boot script, the switch, and that no
    look or theme names data-flip.
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2026-10-14 Ask for the sensors from the look chip, and name the switch for the page
    The first tap on the header's chip is a gesture iOS accepts, so it asks for the orientation sensor before the sheet opens. The switch now reads 'Page turn' and says it is about the page righting itself, not the controller, which follows by itself. The sheet no longer starts the listener; src/tilt.js does that from load.
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2026-10-15 Finish the page turn when auto-rotate parks the page in landscape
    A phone turned right over passes a quarter turn on the way, and with
    auto-rotate on the OS turns the page to landscape there and stays, since
    it has no upside-down portrait to go to. The page then sits on its side
    for the player, and the first cut never righted it: it took the OS's 90
    out of the reading, saw only 90 left, under its 150 threshold, and did
    nothing.
    Decide upside down on the phone's own angle instead, whatever the OS did
    with the page, and turn the page by what the OS left undone: data-flip is
    180 where the page stayed put, 90 or 270 where it was parked in landscape,
    nothing where the OS turned it all the way it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
2026-10-17 Put the page turn behind a small icon beside the look chip, with a popover and a first-visit tip
    The gate's "let the page turn with the phone" button shouted; it is gone.
    Every header now has a small icon before the ◐ chip - a phone with an arrow
    round it - that shows the state (dim on auto, lit while the page is turned,
    filled on yes, struck through on no) and a dot while iOS still has to be
    asked for the sensor. Its tap is the gesture iOS wants, so the prompt comes
    from the icon, and it opens a popover under it: one line on what the turn is
    and the hand switch, auto / no / yes, the same switch the sheet carries as a
    row; one state, localStorage alice.flip. On a touch screen the popover o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
2026-10-17 Show the site only what the play needs: the bench's chrome goes behind data-host
    The walk-cycle viewer, the tile and item sheets and their mode buttons, the
    Solve buttons, the playback and tick sliders, the clock switch and the
    sentences about the keyboard are class dev-only. src/look-boot.js marks
    <html data-host> before paint by the same answer as gateMode (the four dev
    hosts; ?gate=1 on one of them is the site) and styles.css hides the class on
    the site. Nothing leaves the DOM, so gallery.js stays wired; ?autosolve= is
    the bench's only. The status lines are shorter: "0/3 buttons · 0 moves".
    verify-looks checks the classes, the rule and the boot script's hosts, and
    no longer trips on CRL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
2026-10-18 Obfuscate the published JavaScript at deploy time, with a lure for agents
    The deploy now rewrites the staged site in place before uploading it:
    every comment out, every function- and block-local binding renamed to a
    misleading name drawn from the game's own vocabulary, every string literal
    packed into one XOR-ed base64 blob per file behind a one-line decoder,
    whitespace folded with newlines kept, and a note "for automated
    assistants" at the top of every module and page that sends an agent to the
    rabbit hole for "the verified solution" - the flag it finds there is a
    function of the module's path, so a decoy that reaches the scoreboard names
    the file it was lured from. Each module also ends wi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
2026-10-21 Walk the range with a tutorial: Down the Rabbit Hole
    Seventeen steps that watch what the player does and tick themselves off:
    chapter one visits every range's hand level with any controller (wake,
    the trigger, the tune, a measurement then a skip, the lock's no then its
    clock, the watchdog, Humpty polite, fallen, opened); chapter two is the
    badge - record and fire, speed, offset, repeat, one badge-only level per
    range. The current step rides as a coach line between the mode bar and the
    panels in every look, and as a checklist in a Learn panel; a step arms its
    range, picks its level and in the phone looks shows that panel. Any step
    can be skipped or clicked, the whole thing started over, and p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
2026-10-21 Share the tutorial's coach between pages
    The coach line and the Learn panel were drawn by glitch.js; the stages page
    is about to carry a tutorial too, so the rendering moves to src/coach.js
    (mountCoach: #coach, #learnPanel, skip / learn / start over, a page's
    prepare hook) and its styles from src/glitch.css to styles.css, with a
    small controls legend (p.keys) alongside. The next step is prepared in a
    microtask after the completing event, so the press that finishes a step
    never lands on the range it arms.
2026-10-21 Teach the stages too: A Caucus Race, undo, and a clock that waits
    A Learn mode on index.html with a 14-step tutorial over the two rooms,
    fed by what the stages do: the tea party (wake, step, shove, lever,
    button, undo, reset, win) and the gauntlet (first press, wait, caught,
    restart, a button across the corridor, out). Each step arms its stage
    and, on a phone, shows it.
    The rooms themselves get friendlier on every host: a controls legend
    under each title; the tea party keeps a history so B, Backspace or the
    Undo button take a move back, warns when a rock is lost in a corner and
    says why a move bumped; the gauntlet's clock holds after every restart
    until the first input, which is taken at on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
2026-10-27 The level studio: hand tools, a tutorial and an assistant's bridge
    The maker's editor grows into a studio for building rooms by hand: a
    pencil, a line, a rectangle (Shift fills), a fill and a pick, mirrored
    strokes, the room flipped, turned or moved with its routes, undo and redo,
    zoom, and overlays drawn from the solver's own bookkeeping - the cells a
    rock is lost on, Alice's reach, the last solution's path, the cast's
    sight. Six starters, a seeded generator ("Surprise me": knobs, a seed that
    names the room, only solvable draws), a shelf of rooms, a verdict with the
    shoves and a word for the difficulty, a picture of the board, a keys
    dialog, auto-check. "Painting the Roses" walks a first vi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
2026-11-04 Find a range module by its levels, not only a room by its rows
    loadStage in src/seal.js took the export with rows since the community rooms landed (2eee864), so the watch and the dog - ranges with no map - were 'no stage' and glitch.html refused to open on main. stageOf(mod) accepts rows or levels and is the one finder; verify-range.mjs pins the shape of every shipped module.
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2026-11-04 Move the glitch range's level checks into a module the maker can call
    verify-range.mjs judged every shipped level inline: the hand and badge
    budgets, a replay that wins and one that loses, a hand simulated on the
    level, the reference attacker on the lock and the wall with its cost, the
    rules exercised on the level. Nothing of it could be reused by the level
    maker, so a community range level would have had a checker of its own.
    src/rangecheck.js now holds that judgement, pure and DOM-free, as
    rangeCheck(level) over a level written as data ({ name, range, id, ...the
    range's fields }), with rangeLint for the fields' types and ranges (the
    listing parses with one target, pools are badge buttons,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
2026-11-04 Let the obfuscator's bracket walkers pass a close-and-open template piece
    A template literal with adjacent interpolations (a, b and c one after the other) is cut into pieces of which the middle ones both close one interpolation and open the next. matchOf counted the close first and returned at the first such piece as if the literal had ended; the walk that then started on the second piece could never balance and the renamer threw 'unbalanced brackets'. Such a piece is net zero mid-walk (a plain opener or closer only when a walk starts on it) in matchOf, matchOfBack and the shorthand-property walk. Pinned in verify-obfuscate's regressions.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
